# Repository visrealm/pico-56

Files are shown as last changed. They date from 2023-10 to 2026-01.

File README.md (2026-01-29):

# PICO-56
My [HBC-56](https://github.com/visrealm/hbc-56), a 65C02/TMS9918A homebrew computer on a backplane, fully emulated on a Raspberry Pi Pico.

<p align="left"><a href="https://github.com/visrealm/hbc-56">HBC-56</a></p>

Emulating the following HBC-56 hardware
* 65C02 CPU
* 65C22 VIA
* TMS9918A VDP
* Dual AY-3-8910 PSGs
* Dual NES controller inputs
* PS/2 keyboard input
* 96KB Banked RAM/ROM

Making use of my various emulation libraries (and more):

* [vrEmu6502](https://github.com/visrealm/vrEmu6502) - 6502/65C02 CPU emulation library (C99)
* [vrEmu6522](https://github.com/visrealm/vrEmu6522) - 6522/65C22 VIA emulation library (C99)
* [vrEmuTms9918](https://github.com/visrealm/vrEmuTms9918) - TMS9918A/TMS9929A VDP emulation library (C99)

Follow along on YouTube here: [youtube.com/@TroySchrapel](https://youtube.com/@TroySchrapel)

## Build Status

| | Windows | Linux | macOS |
|---|---|---|---|
| **Pico** |  |  |  |
| **Pico2** |  |  |  |

## Development environment

To build PICO-56, you'll need:
- CMake 3.12 or later
- ARM cross-compilation toolchain
- Python 3.x with Pillow library
- Git with submodules support

### Quick Start
 
```bash
git clone --recursive https://github.com/visrealm/pico-56.git
cd pico-56 && mkdir build && cd build
cmake -DCMAKE_BUILD_TYPE=Release -DPICO_SDK_FETCH_FROM_GIT=ON ..
make -j4  # Linux/macOS
```

For detailed platform-specific build instructions, troubleshooting, and advanced options, see **[BUILDING.md](BUILDING.md)**.

## Episodes
In the Episodes, I build the code from the ground up and provide a number of working demos. These are a work in progress with more to come as the videos come out.
#### [Episode 1 - VGA](episodes/ep01-vga)
In this episode, I build a VGA circuit on the Raspberry Pi Pico and write an intitial generic VGA output library and a number of VGA test programs from a test pattern through to moving sprites and an 800x600 framebuffer.

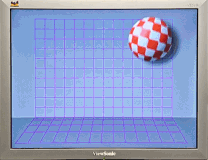
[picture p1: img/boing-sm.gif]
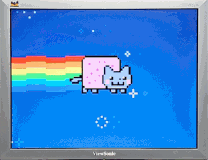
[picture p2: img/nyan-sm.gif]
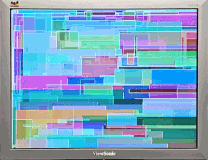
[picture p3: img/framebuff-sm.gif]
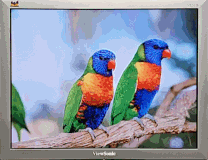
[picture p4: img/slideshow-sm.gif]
[](episodes/ep01-vga/ep01-vga-04-boing)  [](episodes/ep01-vga/ep01-vga-05-nyancat)  [](episodes/ep01-vga/ep01-vga-06-framebuffer)  [](episodes/ep01-vga/ep01-vga-09-slideshow)

#### [Episode 2 - TMS9918A](episodes/ep02-tms)
In this episode, I incorporate my TMS9918 library and create some test programs to test the TMS9918 functionality on the Pi Pico.

## Complete kits

Complete PICO-56 kits are now available on Tindie:





Also featured in HackerBox 0103 for those in the US:



## Gerbers

Gerbers for the PICO-56 v1.4 are now available. See [/schematics](schematics)

If you would like to support this project, you can [order your PCBs from my PCBWay project link](https://www.pcbway.com/project/shareproject/PICO_56_Retro_Computer_on_a_Pi_Pico_515c59b8.html)

## Schematics

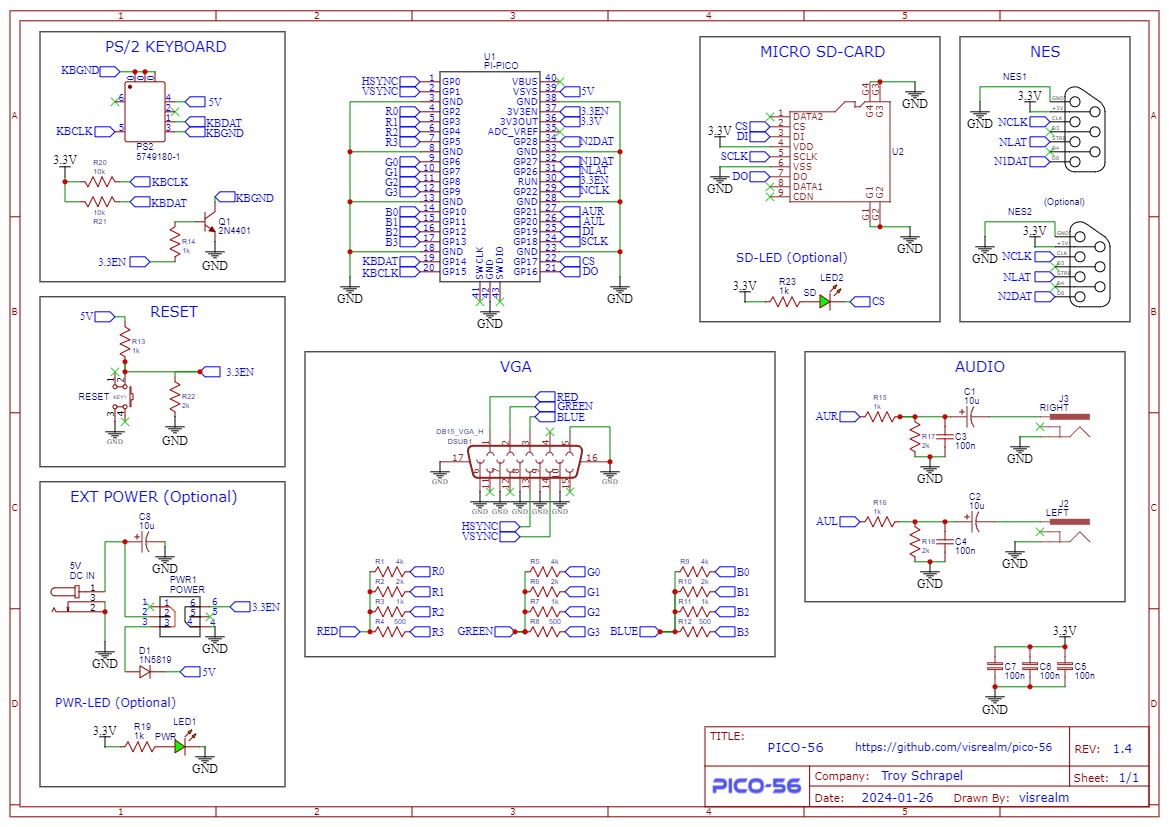
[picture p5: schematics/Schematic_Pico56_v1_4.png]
PICO-56 v1.4
<p align="left"></p>

## Bill of materials

| Qty. | Description | Code |
|---|---|---|
| 1 | PICO-56 PCB | PCB |
| 5 | 100nf (104) ceramic capacitor | C3,C4,C5,C6,C7 |
| 3 | 10uf (106) electrolytic capacitor | C8,C1,C2 |
| 3 | 4kΩ 0.25w resistor (3.9kΩ ok) | R1,R5,R9 |
| 2 | 10kΩ 0.25w resistor | R20,R21 |
| 6 | 2kΩ 0.25w resistor | R22,R2,R6,R10,R17,R18 |
| 9 | 1kΩ 0.25w resistor | R3,R7,R11,R13,R14,R15,R16,R19,R23 |
| 3 | 500Ω 0.25w resistor (510Ω ok) | R4,R8,R12 |
| 1 | 2N4401 transistor | Q1 |
| 1 | 1N5819 diode | D1 |
| 1 | Blue LED | LED1 |
| 1 | Green LED | LED2 |
| 1 | Push button | KEY1 |
| 1 | Push button (locking) | PWR1 |
| 1 | Barrel jack connector | 5V |
| 1 | VGA connector | DSUB1 |
| 2 | RCA connector | J2,J3 |
| 2 | NES connector | NO1,NO2 |
| 1 | PS/2 connector | PS2 |
| 1 | Raspberry Pi Pico (plus headers)  | U1 |
| 1 | MicroSD card connector | U2 |

There is a more detailed BOM in the [/schematics](schematics) folder. Alternatively, I have created a [Mouser project](https://www.mouser.com/ProjectManager/ProjectDetail.aspx?AccessID=8431486f76) for this which contains everything except for the NES connectors which can be obtained from AliExpress.

## 3D Printed case

A 3D printed case is available. All STLs are in the [/case](case) directory.

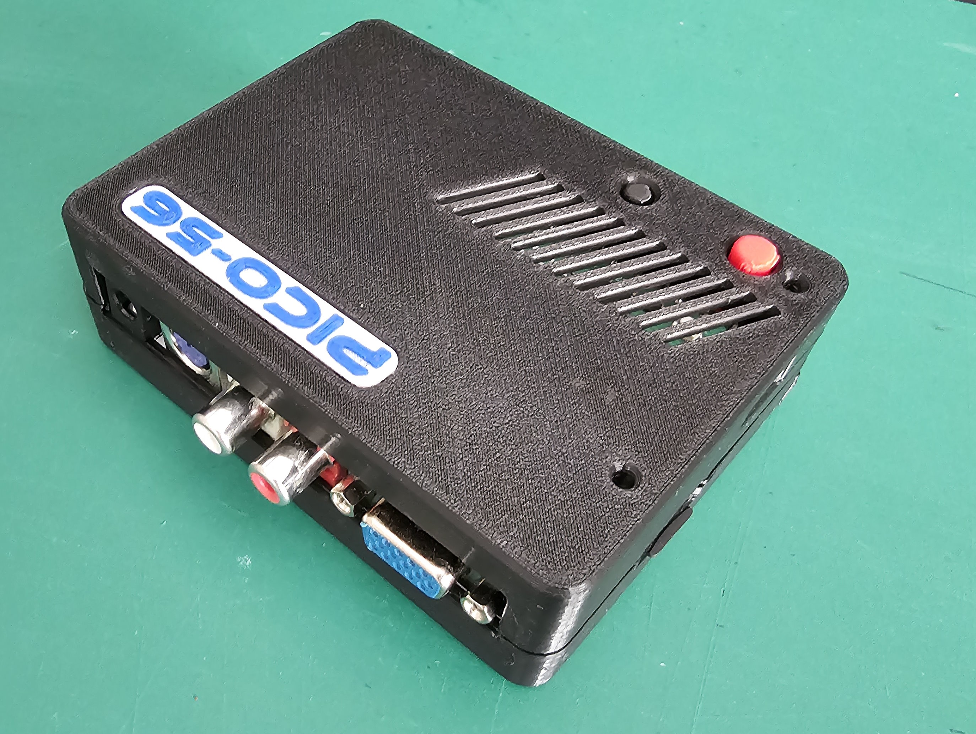
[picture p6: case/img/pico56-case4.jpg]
PICO-56 case
<p align="left"></p>

## Videos
PICO-56 - Introduction (https://www.youtube.com/watch?v=Nj_KkYn7YaA)

PICO-56 - Full Kit Build (https://www.youtube.com/watch?v=1hwMNQ1DXIU)

### Thanks

Thanks to [PCBWay](https://pcbway.com/g/186WQ9) for supporting this project.

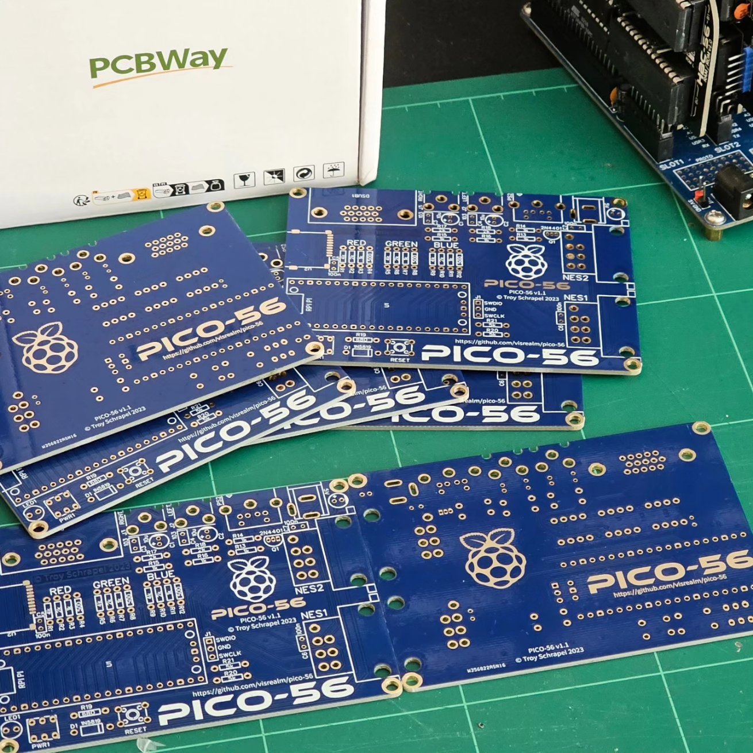
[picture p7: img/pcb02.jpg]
PICO-56
<p align="left"></p>

## Resources

* [Windows Development Environment Installer](https://github.com/raspberrypi/pico-setup-windows/releases)
* [Raspberry Pi Pico C/C++ SDK (PDF)](https://datasheets.raspberrypi.com/pico/raspberry-pi-pico-c-sdk.pdf)
* [HBC-56 Project](https://github.com/visrealm/hbc-56)
* [vrEmu6502 - 6502 CPU Emulation Library](https://github.com/visrealm/vrEmu6502)
* [vrEmu6522 - 6522 VIA Emulation Library](https://github.com/visrealm/vrEmu6522)
* [vrEmuTms9918 - TMS9918A VDP Emulation Library](https://github.com/visrealm/vrEmuTms9918)

## License
This code is licensed under the [MIT](https://opensource.org/licenses/MIT "MIT") license

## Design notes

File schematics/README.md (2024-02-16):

# Schematics

Version 1.4 of the schematic and [gerbers](Gerber_PCB_Pico56_v1_4.zip) are avilable now. 



## Changelog

#### v1.4

* Removed Raspberry Pi logo
* Added PCBWay logo

#### v1.3

* Fixed reversed transistor Q1
* Increased distance between R23 and mounting hole
* Increased hole size for power switch pins

#### v1.2

* Initial public release

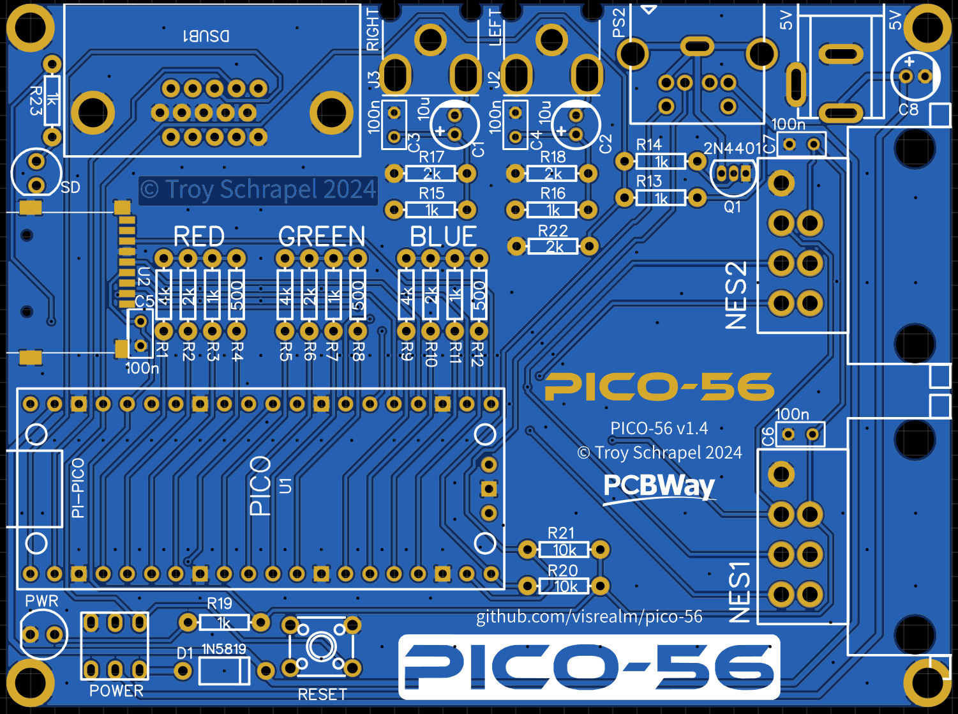
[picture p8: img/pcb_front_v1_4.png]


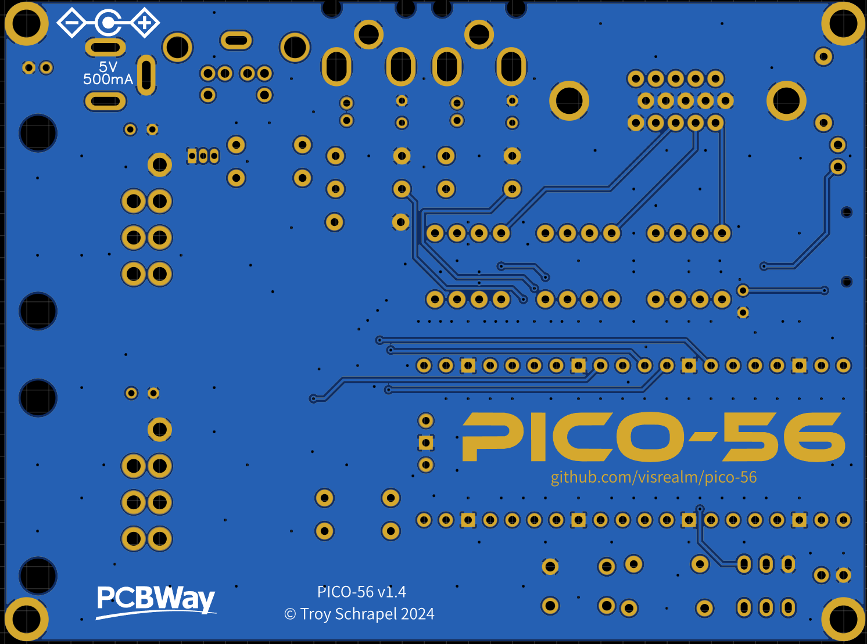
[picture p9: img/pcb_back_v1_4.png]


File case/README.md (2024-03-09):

## 3D Printed Case

I've had a first pass at designing a 3D printed case for the PICO-56. The PCB wasn't really designed with a case in mind, so there are some compromises. Primarily, it doesn't screw together. It clips together.

### Print details

* 0.2mm layer height
* Supports to bed only
* Top and base printed with flat surface down
* Buttons printed on their sides with supports and raised 0.2mm
* Badge printed with a pause for filament swap
* Photos from Creality Ender 3 V3 KE using 1.75mm Creality Hyper Series PLA

### Threaded inserts

The threaded inserts I've used are M3.5x5.7x4.6

### Gallery

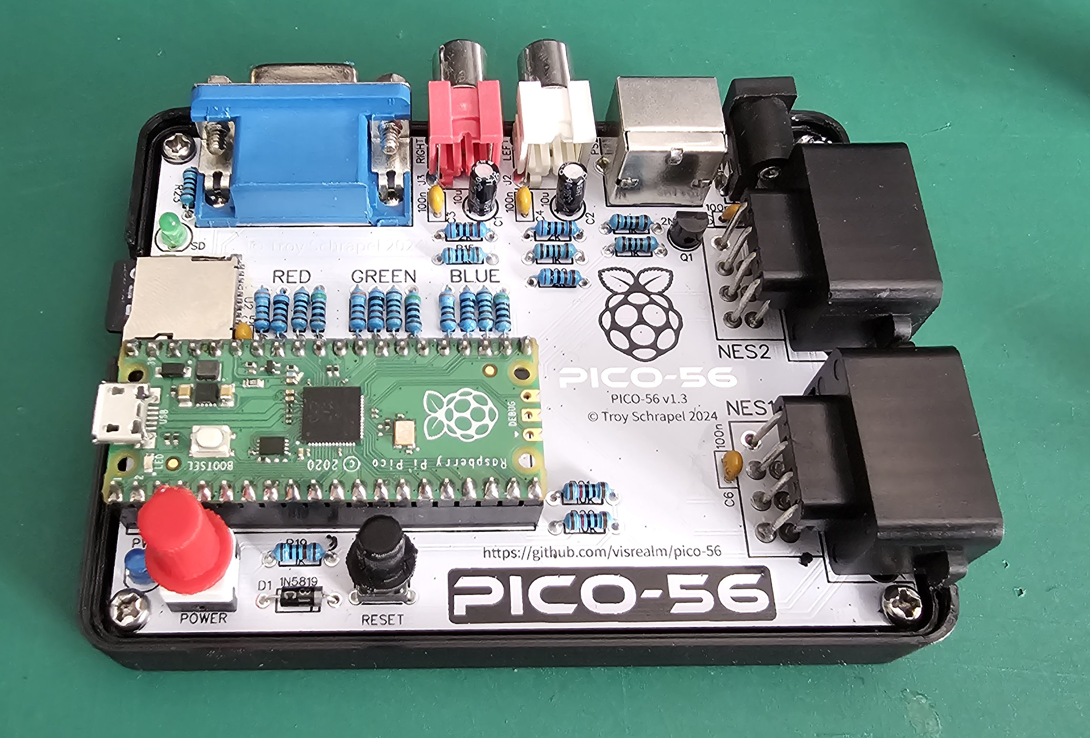
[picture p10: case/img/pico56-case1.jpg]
PICO-56 - Case

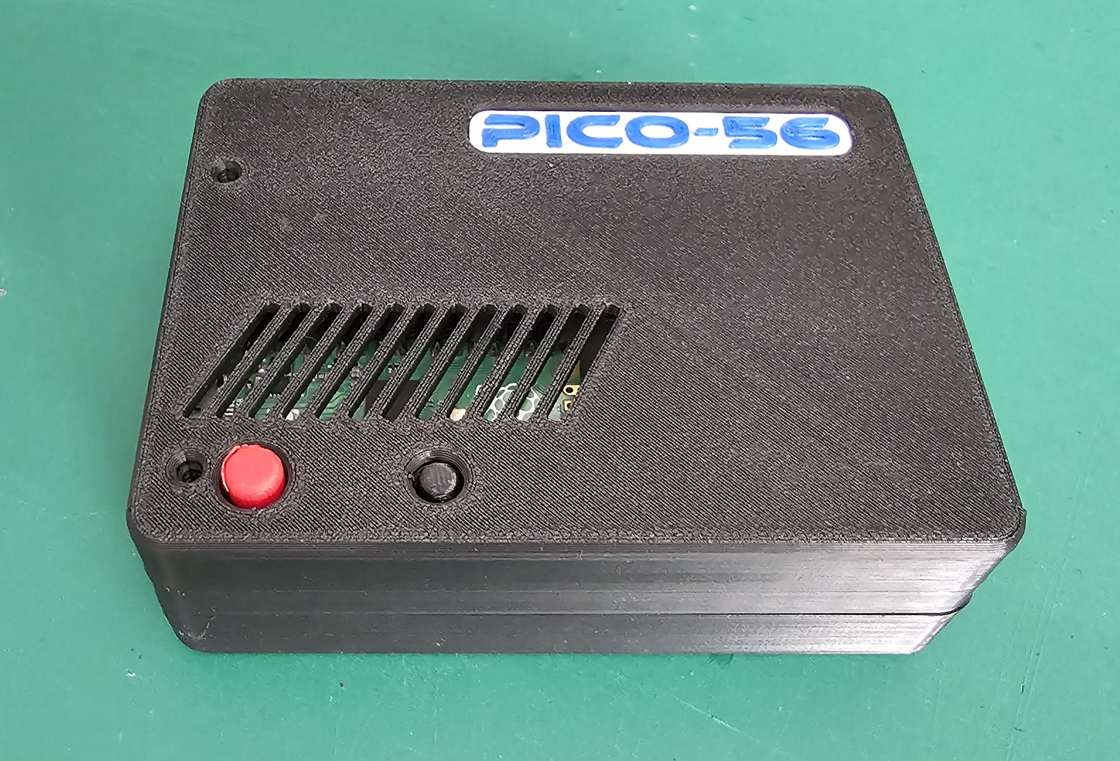
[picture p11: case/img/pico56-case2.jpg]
PICO-56 - Case

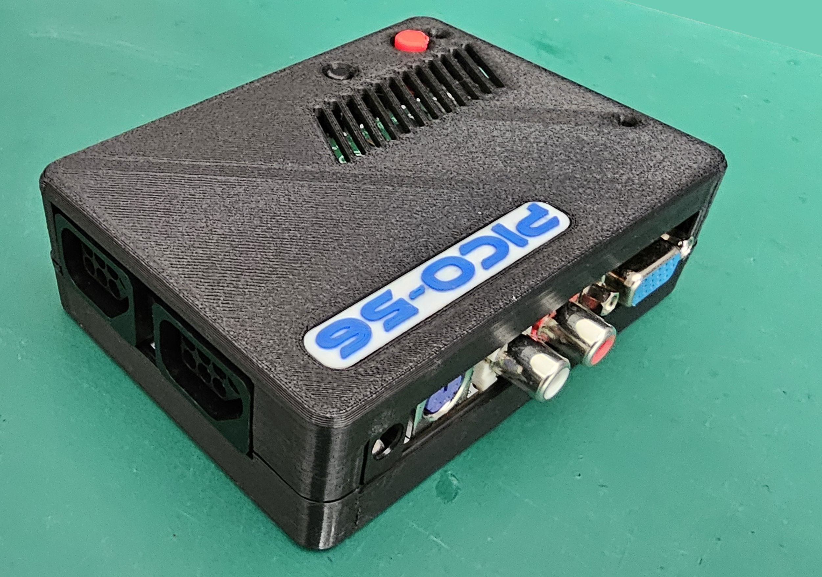
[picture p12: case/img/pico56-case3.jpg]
PICO-56 - Case

PICO-56 - Case
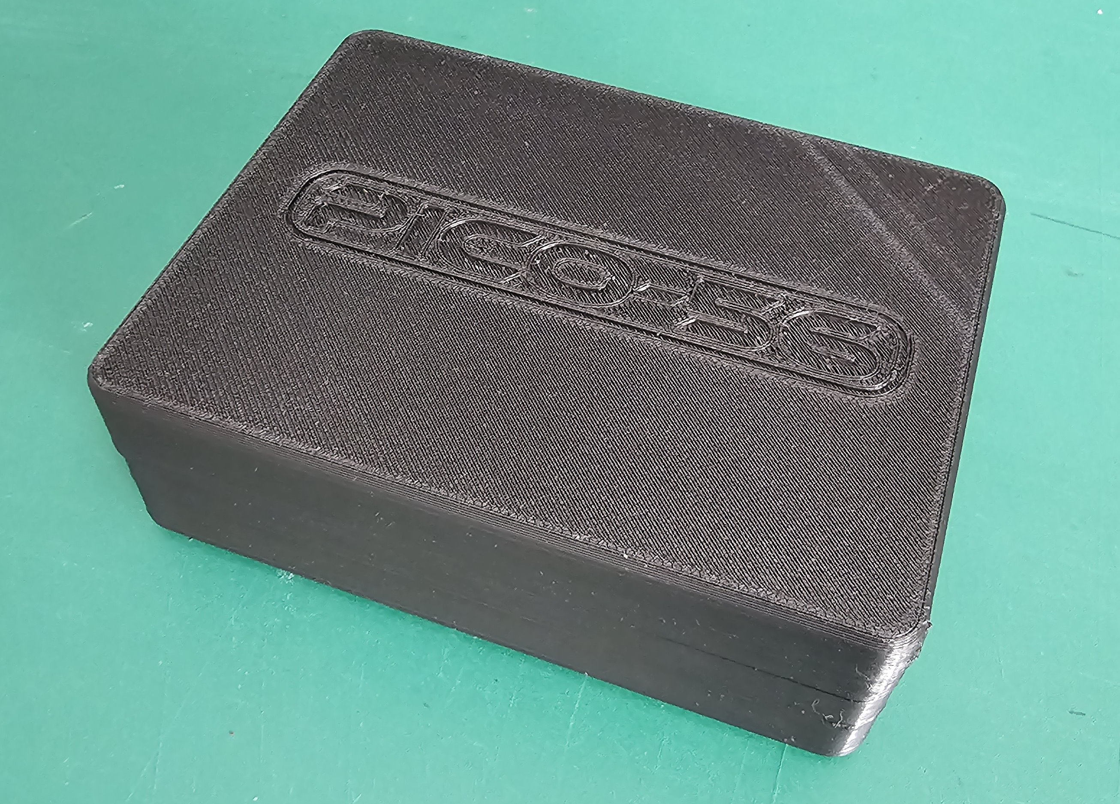
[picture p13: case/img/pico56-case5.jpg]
PICO-56 - Case


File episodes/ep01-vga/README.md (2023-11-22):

# Episode 1 - VGA

In this episode, I build a VGA circuit on the Pico and write an intitial generic VGA output library and a number of VGA test programs from a test pattern through to moving sprites and an 800x600 framebuffer.

## Schematic

For this episode, we start the build by adding a VGA connector and a reset button to the Pico. 

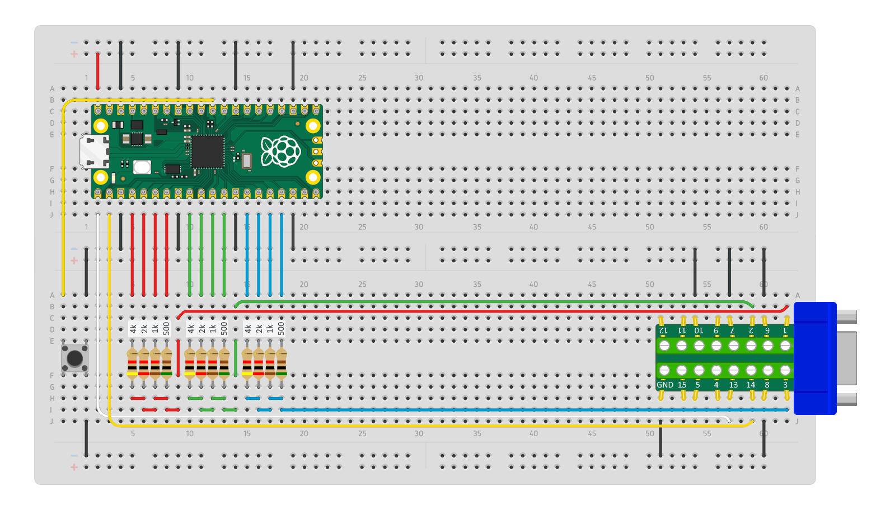
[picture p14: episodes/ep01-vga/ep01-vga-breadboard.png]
VGA on Breadboard


Full schematic here: [ep01-vga-schematic.pdf](ep01-vga-schematic.pdf)

## Example programs

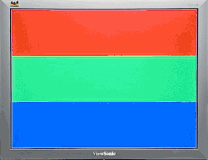
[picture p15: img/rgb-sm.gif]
rgb example video
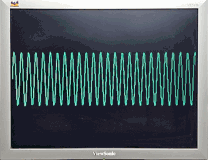
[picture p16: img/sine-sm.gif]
sine example video
| **[00 - VGA Sync](ep01-vga-00-sync)<br><br>Introduction to using the Pi Pico's Programmable Input/Output (PIO) to generate a configurable VGA sync signal.<br>**  | **[01 - VGA RGB](ep01-vga-01-rgb)<br><br><br>Adding a second PIO state machine to handle the VGA's RGB signals. Fill the VGA display with a solid color.** | **[03 - Sine Wave](ep01-vga-03-sine)<br><br><br>Generate an animated sine wave on the display.** |
|:--:|:--:|:--:|
| **[04 - Boing](ep01-vga-04-boing)<br><br>boing example video<br>The classic Commodore Amiga Boing demo. Showing animated sprites.** | **[05 - Nyan Cat](ep01-vga-05-nyancat)<br><br>nyan example video<br>It's a meme. The Nyan Cat.** | **[06 - Frame Buffer](ep01-vga-06-framebuffer)<br><br>framebuffer example video<br>Here, we use a 320x240x12bpp framebuffer to output graphics.** |
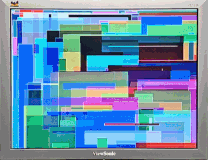
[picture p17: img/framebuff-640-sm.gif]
framebuffer 640x480 example video
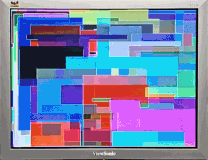
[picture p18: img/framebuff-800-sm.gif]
framebuffer 800x600 example video
| **[07 - Frame Buffer (640 x 480)](ep01-vga-07-framebuffer-640)<br><br><br>We can't fit a 640x480x12bpp framebuffer, but we can do 4bpp using a palette.** | **[08 - Frame Buffer (800 x 600)](ep01-vga-08-framebuffer-800)<br><br><br>Can we push it to 800 x 600?** | **[09 - Slideshow](ep01-vga-09-slideshow)<br><br>slideshow example video<br>A picture show** |

## VGA library

This VGA code is much more capable that is required for the future emulation of the TMS9918A and could be used stand-alone. This is the interface:

```c++
typedef void (*vgaScanlineFn)(uint16_t y, uint16_t pixels[VGA_VIRTUAL_WIDTH]);

typedef struct
{
  vgaScanlineFn scanlineFn;
} VgaInitParams;

void vgaInit(VgaInitParams params);
```

To use the library, you just need to implement a `vgaScanlineFn()` function which could be as simple as copying out data from a framebuffer:

```c++
/* my framebuffer */
uint16_t __aligned(4) frameBuffer[VGA_VIRTUAL_WIDTH * VGA_VIRTUAL_HEIGHT];

/* my scanline function - copy from my framebuffer */
void frameBufferScanline(uint16_t y, uint16_t pixels[VGA_VIRTUAL_WIDTH])
{
  memcpy(pixels, frameBuffer + y * VGA_VIRTUAL_WIDTH, VGA_VIRTUAL_WIDTH * sizeof(uint16_t));
}
```

Example `main()` function to initialize the VGA using the above framebuffer implementation:

```c++
int main(void)
{
  /* set up my VGA */
  VgaInitParams params;
  params.scanlineFn = frameBufferScanline;
  vgaInit(params);
  
  /* TODO: write to my framebuffer here */

  while (1)
  {
    /* TODO: or even in here */
	
    tight_loop_contents();
  }

  return 0;
}
```

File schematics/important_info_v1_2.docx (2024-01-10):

IMPORTANT INFORMATION

PCB v1.2

1. Transistor Q1 should be reversed. Mount with the flat side of the transistor facing the bottom of the PCB.

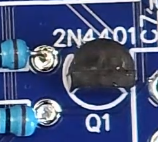
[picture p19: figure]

2. Capacitors C3 and C4 are marked 103. The supplied 100nF (104) capacitors should be used here.

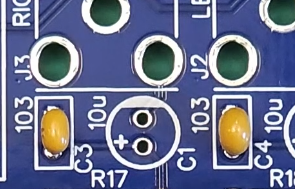
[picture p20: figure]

For latest information, firmware, software, tutorials, check out:

GitHub: https://github.com/visrealm/pico-56

YouTube: https://youtube.com/@TroySchrapel

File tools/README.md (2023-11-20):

Any custom tools required for the project go here:

# [img2carray.py](img2carray.py)

An image converter. Converts images into C arrays for direct use in a PICO-56 program.

The format of the image data will be `const uint16_t[]` for 24 or 32 bit images and will be a combined `const uint16_t[]` for the palette and a `const uint8_t[]` at 4 bits per pixel for 16 color paletized images and 8 bits per pixel for 256 color paletized images.

Alpha values are also supported.

The output format is `0bAAAABBBBGGGGRRRR` or `0xABGR`.

## Dependencies

The script requires the [Pillow Imaging Library](https://pypi.org/project/Pillow/).

Installation:

```sh
python3 -m pip install --upgrade Pillow
```

## Usage

```sh
python3 img2carray.py [-h] [-v] [-p PREFIX] [-o OUT] [-r RAM [RAM ...]] [-i IN [IN ...]]

Convert images into C-style arrays for use with the PICO-56.

options:
  -h, --help            show this help message and exit
  -v, --verbose         verbose output
  -p PREFIX, --prefix PREFIX
                        array variable prefix
  -o OUT, --out OUT     output file - defaults to base input file name with .c extension
  -r RAM [RAM ...], --ram RAM [RAM ...]
                        input file(s) to store in Pi Pico RAM - can use wildcards
  -i IN [IN ...], --in IN [IN ...]
                        input file(s) to store in Pi Pico ROM - can use wildcards
```

### input

A filename or glob (wildcards) to convert. By default, the arrays will be stored in the Pi Pico flash/ROM. TO have an image array assigned to be stored in RAM, pass it in using the -r / --ram command-line prefix.

### output

Optional parameter to specify a single output file.

By default, the output files will be named the same as the input file(s) with a .c/.h extension. This option allows you to combine multiple images into a single C source. A header file of the same name is also generated.

## Example usage

```sh
python img2carray.py -i res/*.png -o images.c
```

Will generate images.c and images.h containing all .png images in the res directory.

## CMake integration

[The root CMakeLists.txt](../CMakeLists.txt) contains a `visrealm_generate_image_source()` function which can be used to integrate this tool into your build process.

```sh
visrealm_generate_image_source(<program-name> <output-file> <rom-images> [<ram-images>])
```

Here is an example usage in your project's CMakeLists.txt:

```sh
visrealm_generate_image_source(${PROGRAM} images res/*.png res/myramimage.png)
```

This function will generate the C source file(s) from the input images and also add the .c file to the `target_sources()`. The generated file(s) will be placed in yout project's build directory.

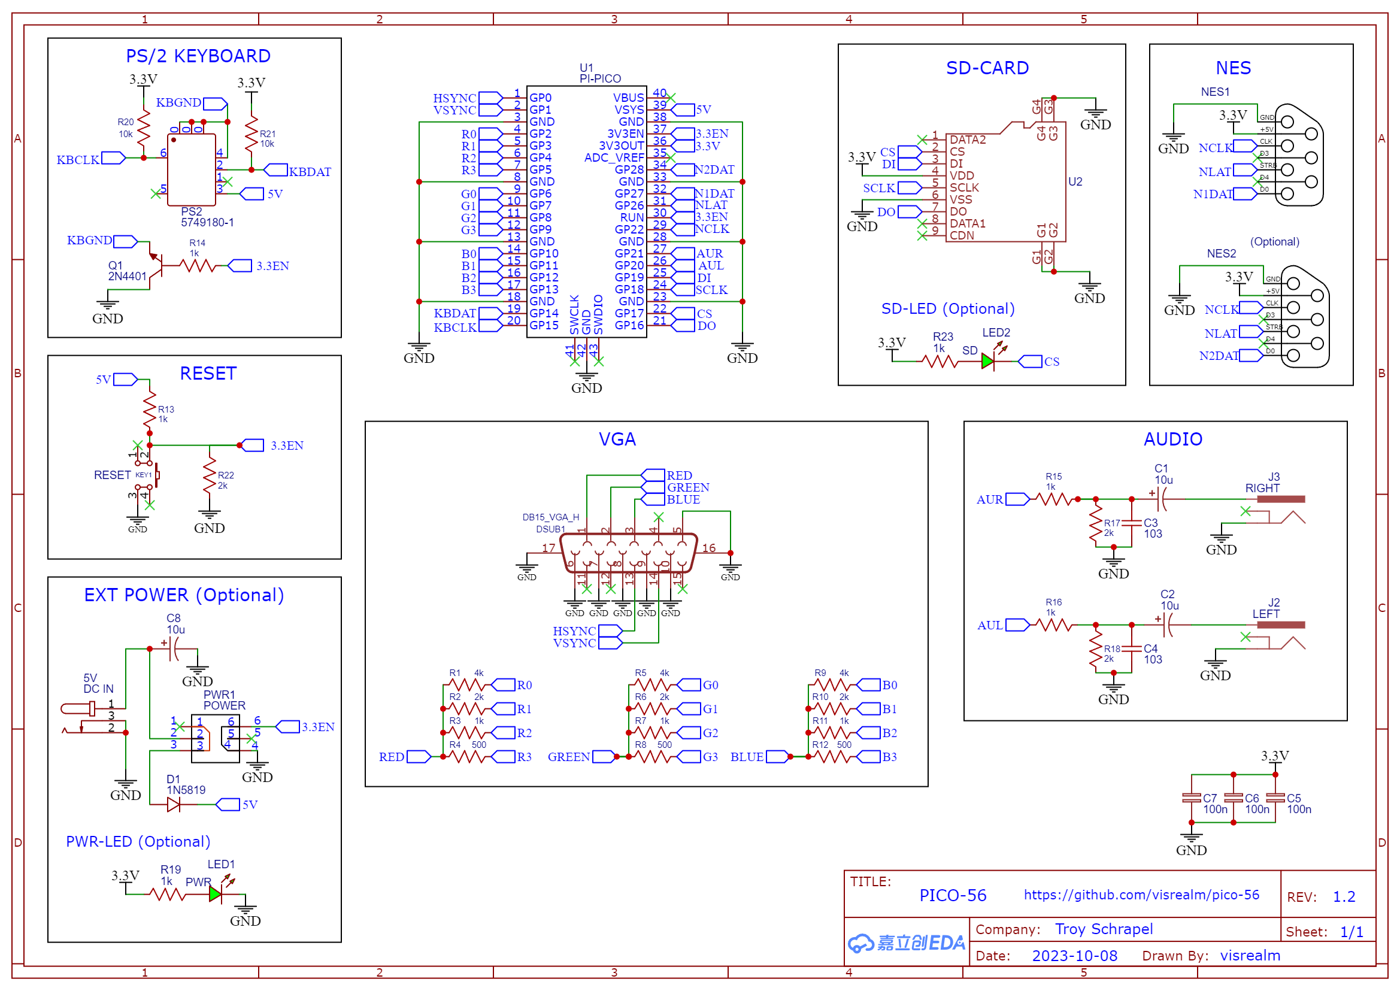
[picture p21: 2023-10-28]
schematics/Schematic_Pico56_v1_2.png

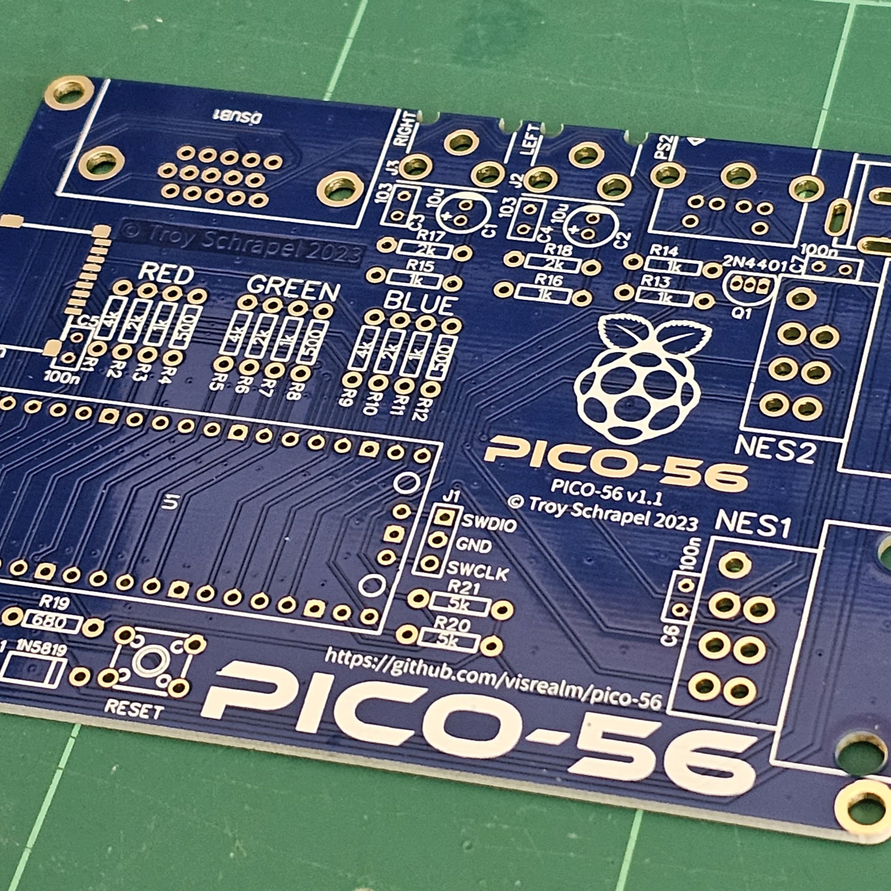
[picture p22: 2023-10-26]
img/pcb01.jpg

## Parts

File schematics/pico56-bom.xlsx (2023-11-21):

ID | Name | Designator | Footprint | Quantity | Manufacturer Part | Manufacturer
1 | PI-PICO | U1 | RASPBERRY-PI-PICO | 1 | SC0915 | Raspberry Pi
2 | SD | LED2 | LED-TH_BD5.0_GREEN | 1 | 333-2SYGD/S530-E2 | EVERLIGHT(台湾亿光)
3 | 1k | R3,R7,R11,R13,R14,R15,R16,R19,R23 | R_AXIAL-0.3 | 9 | MFR-25FTF52-1K | YAGEO
4 | POWER | PWR1 | PB22E08 | 1 | MHPS2285 | APEM
5 | NO | U2 | TF-SMD_TFCARD_ST-TF-003J | 1 | ST-TF-003A
6 | 2k | R22,R2,R6,R10,R17,R18 | R_AXIAL-0.3 | 6 | MFR-25FTF52-2K | YAGEO
7 | 10k | R20,R21 | R_AXIAL-0.3 | 2 | MFR-25FTF52-10K | YAGEO
8 | 10u | C8,C1,C2 | CAP-D5.0×F2.0 | 3 | ESK106M016AC3AA | KEMET
9 | 100n | C5,C6,C7 | RAD-0.1 | 3 | K104K10X7RF5TL2 | Vishay
10 | NES1 | NO1 | NES CONTROLLER 7 PIN FEMALE CONNECTOR WITH MOUNT PEGS | 1 | 5056026433198 | ZedLabz
11 | LEFT | J2 | RCA | 1 | PJRAN1X1U03AUX | Switchcraft
12 | RIGHT | J3 | RCA | 1 | PJRAN1X1U03AUX | Switchcraft
13 | NES2 | NO2 | NES CONTROLLER 7 PIN FEMALE CONNECTOR WITH MOUNT PEGS | 1 | 5056026433198 | ZedLabz
14 | DC IN | 5V | DC-IN-TH_DC005 | 1 | DC005-2.0MM | SOFNG
15 | 5749180-1 | PS2 | PS2-TH_6P-P2.05-S2.49_L12.8-W14.0-M | 1 | 5749180-1 | TE Connectivity
16 | RESET | KEY1 | KEY-TH_4P-L6.0-W6.0-P4.50-LS6.5 | 1 | K2-1102DP-E4SW-04 | 韩国韩荣
17 | 4k | R1,R5,R9 | R_AXIAL-0.3 | 3 | MFR-25FTF52-4K | YAGEO
18 | 500 | R4,R8,R12 | R_AXIAL-0.3 | 3 | MFR-25FTF52-500R | YAGEO
19 | 103 | C3,C4 | RAD-0.1 | 2 | K103K10X7RF5UL2 | Vishay
20 | 2N4401 | Q1 | TO-92-3_L5.1-W4.1-P1.27-L | 1 | 2N3904 | SEMTECH
21 | PWR | LED1 | LED-TH_BD5.0_GREEN | 1 | 333-2SYGD/S530-E2 | EVERLIGHT(台湾亿光)
22 | 1N5819 | D1 | DO-41_BD2.4-L4.7-P8.70-D0.9-RD | 1 | 1N4007W | BLUE ROCKET
23 | DB15_VGA_H | DSUB1 | DB15-VGA-H | 1 | L77HDE15SD1CH4R | Amphenol

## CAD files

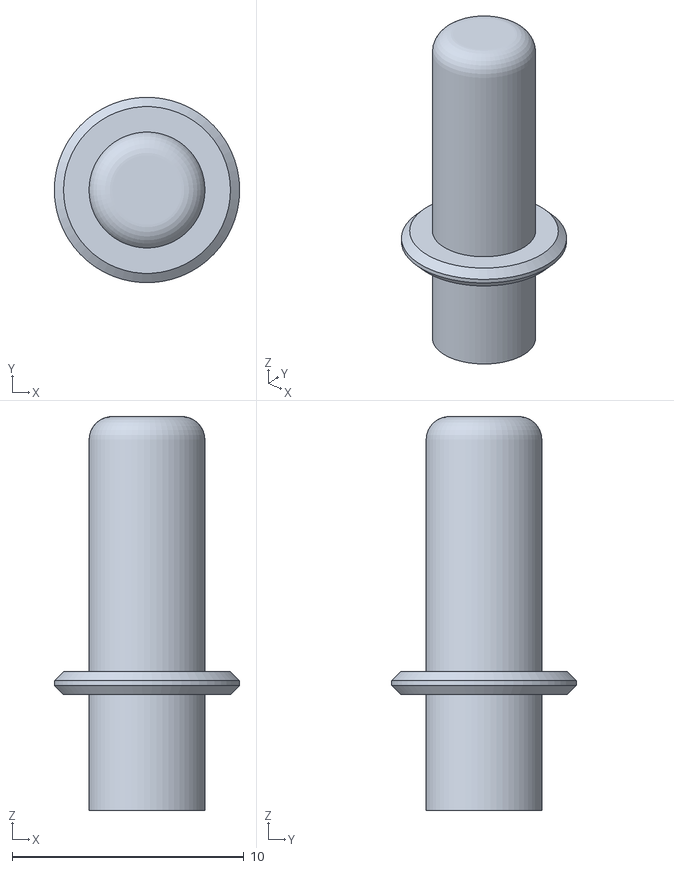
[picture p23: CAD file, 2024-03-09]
case/p56-reset-v1-5.stl
8.00 x 7.99 x 17.0

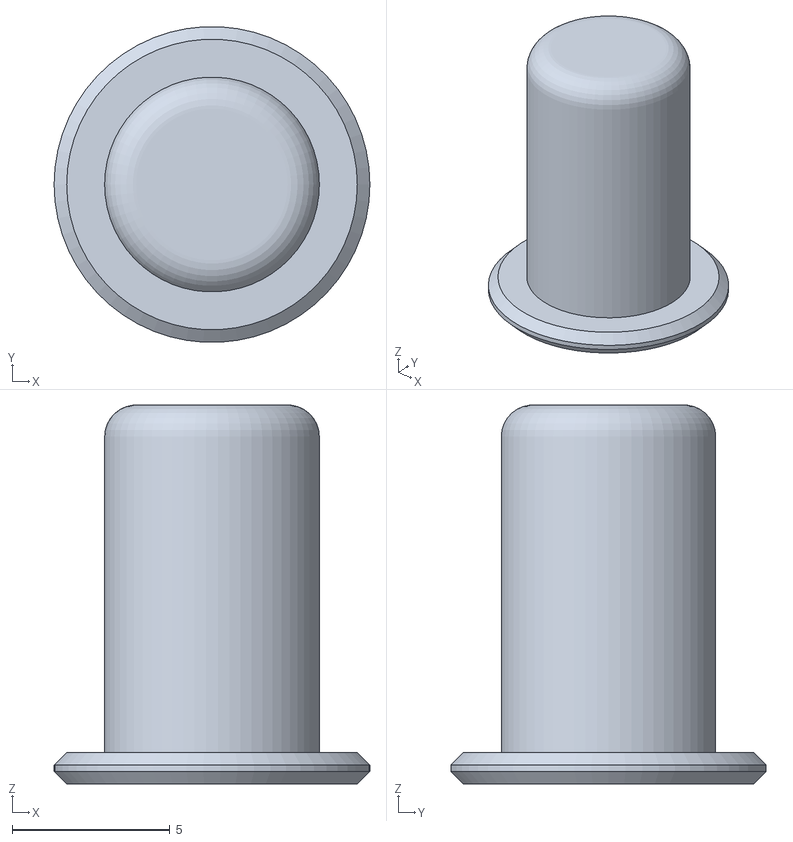
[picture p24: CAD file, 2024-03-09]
case/p56-power-v1-5.stl
10.00 x 9.99 x 12.0

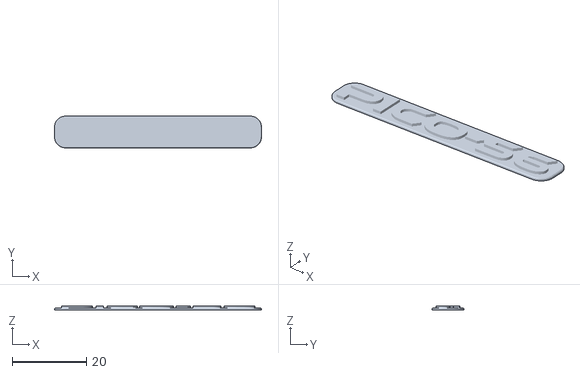
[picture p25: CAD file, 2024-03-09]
case/p56-badge-v1-5.stl
55.9 x 8.60 x 1.20

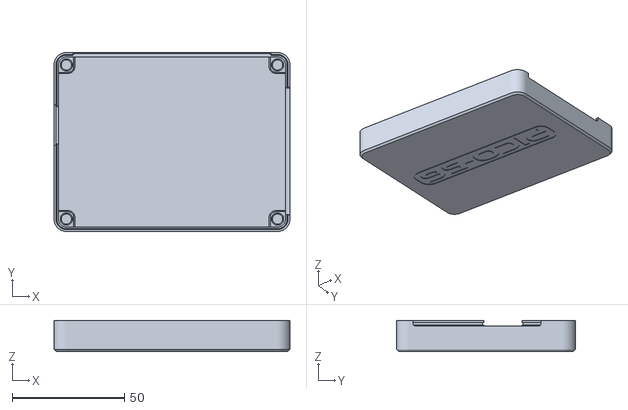
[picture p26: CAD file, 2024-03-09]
case/p56-bottom-v1-5.stl
105.1 x 79.7 x 14.0

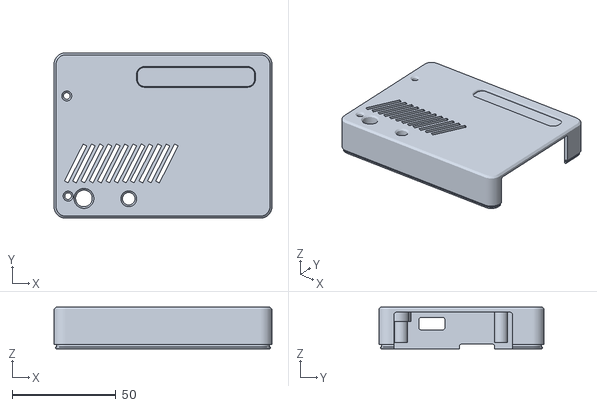
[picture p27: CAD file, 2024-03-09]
case/p56-top-v1-5.stl
105.1 x 79.7 x 20.2

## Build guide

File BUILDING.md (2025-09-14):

# Building PICO-56

This document provides detailed build instructions for the PICO-56 project on different platforms.

## Prerequisites

All platforms require:
- CMake 3.12 or later
- Python 3.x with Pillow library
- ARM cross-compilation toolchain
- Git (with submodules support)

## Windows

### Using the Raspberry Pi Pico VS Code Extension

1. Install [Visual Studio Code](https://code.visualstudio.com/)
2. Install the [Raspberry Pi Pico extension](https://marketplace.visualstudio.com/items?itemName=raspberry-pi.raspberry-pi-pico) from the VS Code marketplace
3. The extension will automatically guide you through installing:
   - Pico SDK
   - ARM GCC toolchain
   - CMake and build tools
   - Python dependencies (including Pillow)

### Building on Windows

#### With VS Code Extension (Recommended)
1. Clone the repository:
   ```cmd
   git clone --recursive https://github.com/visrealm/pico-56.git
   ```
2. Open the `pico-56` folder in VS Code
3. The Pico extension will automatically configure the project
4. Use the extension's build commands or press `Ctrl+Shift+P` and run "Pico: Build"

#### Command Line Building
If you need to build from the command line:
1. Clone the repository:
   ```cmd
   git clone --recursive https://github.com/visrealm/pico-56.git
   cd pico-56
   ```

2. Create build directory and configure:
   ```cmd
   mkdir build
   cd build
   cmake .. -DCMAKE_BUILD_TYPE=Release -DPICO_SDK_FETCH_FROM_GIT=ON
   ```

3. Build:
   ```cmd
   cmake --build . --config Release
   ```

## Linux

### Install Dependencies

#### Ubuntu/Debian:
```bash
sudo apt-get update
sudo apt-get install -y cmake gcc-arm-none-eabi libnewlib-arm-none-eabi build-essential git python3 python3-pip
pip3 install Pillow
```

#### Fedora/RHEL:
```bash
sudo dnf install cmake arm-none-eabi-gcc-cs arm-none-eabi-newlib git python3 python3-pip
pip3 install Pillow
```

#### Arch Linux:
```bash
sudo pacman -S cmake arm-none-eabi-gcc arm-none-eabi-newlib git python python-pip
pip install Pillow
```

### Building on Linux

1. Clone the repository:
   ```bash
   git clone --recursive https://github.com/visrealm/pico-56.git
   cd pico-56
   ```

2. Create build directory and configure:
   ```bash
   mkdir build && cd build
   cmake .. -DCMAKE_BUILD_TYPE=Release -DPICO_SDK_FETCH_FROM_GIT=ON
   ```

3. Build:
   ```bash
   make -j$(nproc)
   ```

## macOS

### Install Dependencies

1. Install Homebrew if not already installed:
   ```bash
   /bin/bash -c "$(curl -fsSL https://raw.githubusercontent.com/Homebrew/install/HEAD/install.sh)"
   ```

2. Install required packages:
   ```bash
   brew install cmake python3
   brew install --cask gcc-arm-embedded
   pip3 install Pillow
   ```

### Building on macOS

1. Clone the repository:
   ```bash
   git clone --recursive https://github.com/visrealm/pico-56.git
   cd pico-56
   ```

2. Create build directory and configure:
   ```bash
   mkdir build && cd build
   cmake .. -DCMAKE_BUILD_TYPE=Release -DPICO_SDK_FETCH_FROM_GIT=ON
   ```

3. Build:
   ```bash
   make -j$(sysctl -n hw.ncpu)
   ```

## Board Variants

The project supports both Raspberry Pi Pico and Pico2. To build for a specific board:

### For Raspberry Pi Pico (default):
```bash
cmake .. -DCMAKE_BUILD_TYPE=Release -DPICO_BOARD=pico -DPICO_SDK_FETCH_FROM_GIT=ON
```

### For Raspberry Pi Pico2:
```bash
cmake .. -DCMAKE_BUILD_TYPE=Release -DPICO_BOARD=pico2 -DPICO_SDK_FETCH_FROM_GIT=ON
```

## Build Outputs

After a successful build, you'll find the following files in the build directory:

- `**/*.uf2` - UF2 files for flashing to the Pico
- `**/*.bin` - Binary files
- `**/*.elf` - ELF executable files

## Flashing to Hardware

1. Hold the BOOTSEL button on your Raspberry Pi Pico while connecting it to your computer via USB
2. The Pico will appear as a USB mass storage device
3. Copy the desired `.uf2` file to the Pico
4. The Pico will automatically reboot and run your program

## Troubleshooting

### Common Issues

#### Missing Python Dependencies
If you get errors about missing PIL/Pillow:
```bash
pip install Pillow
# or on some systems:
pip3 install Pillow
```

#### ARM Toolchain Issues on macOS
If you encounter "cannot read spec file 'nosys.specs'" errors:
```bash
# Uninstall problematic installations
brew uninstall --force arm-none-eabi-gcc arm-none-eabi-binutils
# Install the complete toolchain
brew install --cask gcc-arm-embedded
```

#### CMake Cannot Find SDK
If CMake complains about not finding the Pico SDK, ensure you're using:
```bash
-DPICO_SDK_FETCH_FROM_GIT=ON
```

This will automatically download and configure the correct SDK version.

#### Submodule Issues
If you get errors about missing submodules:
```bash
git submodule update --init --recursive
```

## Building Individual Episodes

The project includes various episode examples in the `episodes/` directory. These are built automatically with the main project. To build only specific episodes, you can use:

```bash
# From the build directory
cmake --build . --target ep01-vga-01-test-pattern
cmake --build . --target ep01-vga-04-boing
# etc.
```

## Development Tips

- Use `CMAKE_BUILD_TYPE=Debug` for debugging builds
- Use `make -j$(nproc)` on Linux or `make -j$(sysctl -n hw.ncpu)` on macOS for parallel builds
- The build system will automatically handle PIO file generation and image conversion
- All dependencies are automatically downloaded when using `PICO_SDK_FETCH_FROM_GIT=ON`

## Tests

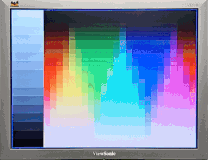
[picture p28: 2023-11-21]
img/testpatt-sm.gif

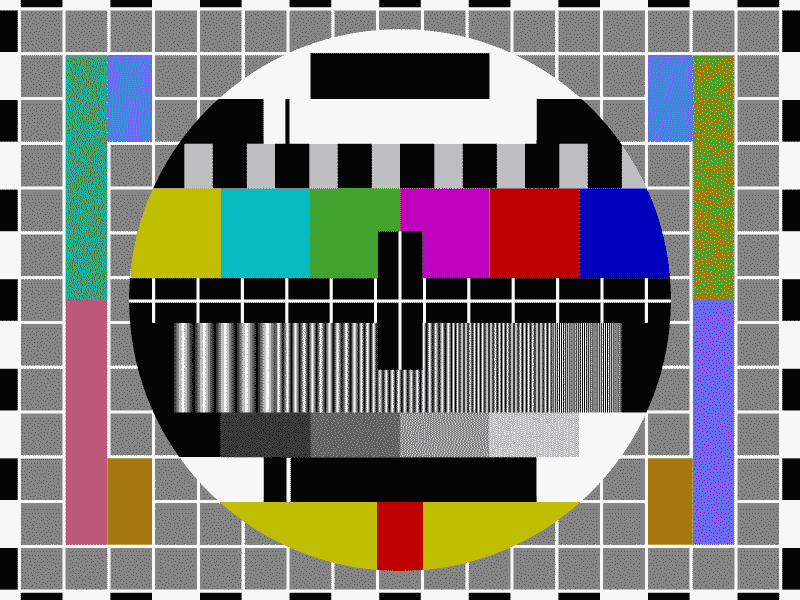
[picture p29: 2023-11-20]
episodes/ep01-vga/ep01-vga-08b-image-800/res/testpatt800x16.png

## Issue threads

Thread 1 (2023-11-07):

Is the AY-3-8910 Pico emulation code available?

cbmeeks, 2023-11-07:
I was wondering if you have released the source for your AY-3-8910 emulation on the Pico.  I am working on a similar project and would really love some information on that.  :-)

Thanks!

visrealm, 2023-11-07:
Hey CB. I'm working on the consumable version now. Here's some snippets from my existing dual AY-3-8910 emulation to get you started. I'm using [my fork of emu2149](https://github.com/visrealm/emu2149).

Globals / magic numbers:
```c
#define PWM_WRAP 1024
#define AUDIO_GPIO 20

PSG* psg0 = NULL;
PSG* psg1 = NULL;

uint audioSlice = 0;
```

Initialization (called once)
```c
void configureAudio()
{
  // init the two PSGs
  int sampleRate = vgaParams.hSyncParams.freqHz;   // I'm updating the audio in my VGA hsync blanking ~37.87KHz
  psg0 = PSG_new(PSG_CLOCK, sampleRate);
  psg1 = PSG_new(PSG_CLOCK, sampleRate);
  PSG_setVolumeMode(psg0, EMU2149_VOL_AY_3_8910);  // AY-3-8910 mode
  PSG_setVolumeMode(psg1, EMU2149_VOL_AY_3_8910);  // AY-3-8910 mode
  PSG_reset(psg0);
  PSG_reset(psg1);

  // init the GPIO pins for PWM
  gpio_set_function(AUDIO_GPIO , GPIO_FUNC_PWM);
  gpio_set_function(AUDIO_GPIO + 1, GPIO_FUNC_PWM);

  audioSlice = pwm_gpio_to_slice_num(AUDIO_GPIO );

  pwm_set_clkdiv_int_frac(audioSlice, 1, 0);
  pwm_set_wrap(audioSlice, PWM_WRAP);
  pwm_set_both_levels(audioSlice, 0, 0);
  pwm_set_enabled(audioSlice, true);
}
```

Updates (called in my hsync event handler at ~37.87KHz:
```c
PSG_calc(psg0);
PSG_calc(psg1);

// mix the various channels from the PSGs how you see fit
uint16_t leftAudio = abs((((int32_t)psg0->ch_out[0] + (int32_t)psg1->ch_out[1] + (int32_t)psg0->ch_out[2] + (int32_t)psg1->ch_out[2]))) * PWM_WRAP >> 14;
uint16_t rightAudio = abs((((int32_t)psg1->ch_out[0] + (int32_t)psg0->ch_out[1] + (int32_t)psg0->ch_out[2] + (int32_t)psg1->ch_out[2]))) * PWM_WRAP >> 14;

pwm_set_both_levels(audioSlice, leftAudio, rightAudio);
```

cbmeeks, 2023-11-08:
Thanks for the response.  I definitely have a lot to learn on this one.  My main goal is to have some sort of PSG from the Pico...all being controlled by a 6502.

visrealm, 2023-11-08:
Oh, so you're using a physical 6502? And the PICO is acting as the RAM/peripherals? One step I failed to mention was reading/writing from/to the virtual PSG(s).  Each PSG will need 3-4 addresses mapped. For example, all of my I/O is mapped at 0x7fxx and my PSGs are mapped at 0x7f40 and 0x7f44.  The way my PSGs are wired on my actual HBC-56, writing to 0x7f40 will latch a register to write to, 0x7f41 will write a register value and reading from 0x7f42 will read a value from the latched register. The address mappings don't matter, but you will need a similar process.

Here's some snippets from the PICO-56 memory read/write functions which show how the various addresses ling to the PSG_readreg/PSG_writereg functions:

```c
#define PSG0_BASE_PORT 0x40
#define PSG1_BASE_PORT 0x44

void cpuMemWrite(uint16_t addr, uint8_t val)
{
  if (addr < 0x7f00)  // RAM
  {
    ram[addr] = val;
  }
  else if (addr < 0x8000) // IO
  {
      switch (addr & 0xff)
      {
        case 0x10:
          vrEmuTms9918WriteData(tms9918, val);
          break;

        case 0x11:
          vrEmuTms9918WriteAddr(tms9918, val);
          break;

        case PSG0_BASE_PORT:
          psg0Reg = val;
          break;

        case PSG0_BASE_PORT | 0x01:
          PSG_writeReg(psg0, psg0Reg, val);
          break;

        case PSG1_BASE_PORT:
          psg1Reg = val;
          break;

        case PSG1_BASE_PORT | 0x01:
          PSG_writeReg(psg1, psg1Reg, val);
          break;

        default:
          // unknown device
          break;
    }
  }
}

uint8_t cpuMemRead(uint16_t addr)
{
  if (addr & 0x8000)     // ROM
  {
    return ROM[addr & 0x7fff];
  }
  else if (addr < 0x7f00)  // RAM
  {
    return ram[addr];
  }
  else    // IO
  {
      switch (addr & 0xff)
      {
        case 0x10:
          {
            return vrEmuTms9918ReadData(tms9918);
          }

        case 0x11:
          {
            uint8_t value = vrEmuTms9918ReadStatus(tms9918);
            releaseInterrupt(TMS_INT);
            return value;
          }

          // <snip> handle keyboard, nes, interrupt controller, etc.

        case PSG0_BASE_PORT | 0x02:
          {
            return PSG_readReg(psg0, psg0Reg);
          }

        case PSG1_BASE_PORT | 0x02:
          {
            return PSG_readReg(psg1, psg1Reg);
          }

        default:
          return 0x00;
      }
    }
  }
}
```

cbmeeks, 2023-11-08:
Thank you for this information!

Yeah, I am designing a new SBC with an actual 6502.  The Pico(s) will act as video, audio, etc.

I will dig into this more when I get back.  Headed out on a nice vacation tomorrow.

Thanks!

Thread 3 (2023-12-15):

Q1 (2N4401) question

g8kuw-tv, 2023-12-15:
Hi Troy - I have built a PICO-56, and it's almost working...

Is Q1 in the Pico-56 schematic shown the wrong way around? I can't see how KBD ground will be pulled low when 3v3 is present.

Thanks

Steve

g8kuw-tv, 2023-12-31:
Thanks Troy!

(I wasn't sure if this was an appropriate place to ask questions.)

vslinuxdotnet, 2024-01-18:
Hello,
Sorry about this question but, what is the propose of this transistor to enable GND in keyboard?
The 3v3_en is to enable (default) the PWD of 3.3v, witch is always high, so the transistor is always on.
Regards,
VS

visrealm, 2024-01-18:
The power and reset buttons are connected to 3.3v_en so the transistor effectively powers off the keyboard when the PICO-56 is "off" (or reset).

Closed 2023-12-31.

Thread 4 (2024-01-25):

Silkscreen / Parts List / Mouser Project not in sync

lloesche, 2024-01-25:
I (admittedly blindly) ordered 5 PCBs using the PCBWay link and 5x the Mouser Project. When assembling everything, I noticed that the silkscreen doesn't even mention 10nf caps, everything is 100nf. But in my Mouser order there were both values delivered. And I believe one of the resistor values was also a different quantity than what I expected based on the values on the board.

Would be good if silkscreen/PCBWay project, Github README, Mouser project, etc. were all in sync.

visrealm, 2024-01-27:
Hi, the parts you've ordered will work just fine with your PCBs. In later revision of the board, I changed the value of the two 10nF caps to 100nF to reduce part type count. The output/result will be almost identical between the two. For the mouser project, some part counts were increased to take advantage of Mouser's bulk pricing. eg. It's cheaper to order 10 of something than 9.

I will update the BOM to reflect later boards.

visrealm, 2024-01-27:
I've updated the Mouser project and BOM to reflect the later boards silkscreen. Have also changed *most* of the mouser project quantities to be actual rather than cheaper bulk discounted values except for the 1K resistors I kept at 10 rather than 9 as it's significantly cheaper that way.

Closed 2024-01-27.

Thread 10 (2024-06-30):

Hardware timers causes crash

cbmeeks, 2024-06-30:
I'm quite sure I have misconfigured the timer example I was trying, but it seems if you try to use one, the video output just stops.

I was mostly curious if you have run into this.

````
// code in vga.c

bool repeating_timer_callback(struct repeating_timer *t) {
    return true;
}

static void vgaLoop() {

    struct repeating_timer timer;
    add_repeating_timer_ms(500, repeating_timer_callback, NULL, &timer);

    while (1) {
        uint32_t message = multicore_fifo_pop_blocking();
        if (message & 0x01) {
            vgaParams.scanlineFn(message & 0xfff, rgbDataBufferOdd);
        } else {
            vgaParams.scanlineFn(message & 0xfff, rgbDataBufferEven);
        }
    }
}

````

visrealm, 2024-07-01:
I suspect the default alarm pool hardware timer IRQ handling is occurring on core 0. This is the same core which is handling the VGA DMA Interrupts (`dmaIrqHandler()`).

Note: `add_repeating_timer_ms()` is a wrapper for `alarm_pool_add_repeating_timer_us()` with `alarm_pool_get_default()` as the first argument.

You might need to manually create an alarm pool on core 1.

See

- https://www.raspberrypi.com/documentation//pico-sdk/group__repeating__timer.html
- https://www.raspberrypi.com/documentation/pico-sdk/group__alarm.html

visrealm, 2024-07-01:
Note: In the actual PICO-56 VGA code ( https://github.com/visrealm/pico-56/blob/main/src/devices/tms9918/vga/vga.c ) you can add a callback for the end of frame.
If you've still having issues using the hardware timer, you could use this to accumulate time in 16.67ms increments. There is also an end of scanline callback which I use to update the PWM audio. So, the PICO-56 audio frequency is tied to the VGA HSYNC frequency (~31KHz).

cbmeeks, 2024-07-01:
Ah, I didn't think about that.  I know very little about the timers on the Pico but I will study that some more.

But now that you mention it, I like the idea of the "end of frame" better anyway.  I needed a timer to flash a cursor but it makes more sense to just put a callback at the end of frame.

Thanks again for your help!  I will try not to pester you with things like this.  :-)

visrealm, 2024-07-02:
I don't mind. No problem at all.

cbmeeks, 2024-07-03:
Thanks again.  I've been taking your underlying source for the VGA and I've added sprite support, PETSCII graphics, text scrolling, etc.

I'm easily pushing 20 sprites per scanline.  Each sprite is 16xYY pixels tall (height definable) and 4 colors like NES (out of multiple palettes) all while on a 256 display.  This $4 Pico (RP2040) is incredible.

Closed 2024-07-01.

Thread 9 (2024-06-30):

BGR vs RGB

cbmeeks, 2024-06-30:
I am curious on how I can change the library to encode pixels as RGB instead of BGR.

I realize I could just swap the wires around (blue pins send to red, etc.) but that doesn't feel right.  Also, when I look at the graphic you have the red pins starting on left.

Is there a way to change this in the code or do I just need to rewire things?

Thanks!

```
void scanline(uint16_t y, uint16_t pixels[VGA_VIRTUAL_WIDTH]) {
    uint16_t c = 0x0000;
    if (y == 0 || y == VGA_VIRTUAL_HEIGHT - 1) c = 0x0000;
    else if (y < 30) c = 0x000f;    // red
    else if (y < 60) c = 0x00f0;    // green
    else if (y < 90) c = 0x0f00;    // blue
    else if (y < 120) c = 0x0f0f;   // fuscia
    else if (y < 150) c = 0x0ff0;   // cyan
    else if (y < 180) c = 0x00ff;   // yellow
    else if (y < 210) c = 0x007f;   // orange
    else if (y < 240) c = 0x0707;   // purple
    for (int x = 1; x < VGA_VIRTUAL_WIDTH - 1; ++x) {
        pixels[x] = c;
    }
    pixels[0] = 0x0000;
    pixels[VGA_VIRTUAL_WIDTH - 1] = 0x0000;
}
```

visrealm, 2024-06-30:
I don't think this can be changed in code. I thought perhaps `sm_config_set_out_shift()` which as a `shift_right` argument, but that doesn't appear to do what I had hoped it would. LSB seems to always be mapped to the lowest IO pin number in the group.

If you must use RGB, I think swapping the R and B pins on the VGA is your best bet.

cbmeeks, 2024-06-30:
Thanks!  I can do that.

Closed 2024-06-30.

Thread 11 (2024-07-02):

Ground plane

sweetlilmre, 2024-07-02:
Hi there again!

First off not a major issue, so let me start with this:
What a fantastic kit! Super well packaged, labelled and straight forward. My pico-56 is working and I'm amped to get into playing with it. I was lucky enough to to have a mate visiting from Oz that could bring it over for me.

While I was soldering up the board, I had some issues with components connected to the ground plane. I have a good temp controlled iron with a medium chisel tip and good thermal mass, that I usually run at 330C. This wasn't sufficient to create a good joint on certain components e.g. some caps, resistors, a transistor leg, pins on some connectors etc. I ended up having to boost the temp up to about 390-400C with uncomfortably long dwell times.

If I'm the only one with this issue, then tough for me, but I would suggest revising the PCB so that the these components are connected via traces through an island to the ground plane to make assembly easier.

Thanks for the awesome project.

visrealm, 2024-07-03:
Thanks Peter.

You are the second person to mention this. The other was one of the giveaway winners.

I run a TS-100 with the BC2 tip at 375C. I haven't had the same issues having assembled ~25 of these, but certainly can see that it could be a problem.

If I make another revision of the board, I will certainly look to reduce the ground plane to pad connection thickness.

sweetlilmre, 2024-07-03:
Thank you, I'll close this.

Closed 2024-07-03.

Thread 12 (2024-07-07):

How does the audio emulation work?

cbmeeks, 2024-07-07:
I realize you forked the emu2149 library and added more code for the Pico.

It seems to be pretty straightforward to get the audio piece to work (using AY-3-8910 mode).  However, nothing seems to work on my setup.

I suspect that you have to call the `audioUpdate()` very quickly?  I believe you are calling it at the end of each horizontal scanline.
Unfortunately, that won't work for my project as I need a more "general purpose" implementation (called from a 6502).

At the very least, what I am doing is something like:

    // setup code
    audioInit(3579545 / 2, 44100);
    audioWritePsg0(7, 0b00111110);
    audioWritePsg0(8, 0b00001111);

    // main loop
     audioWritePsg0(0, 223);
    audioWritePsg0(1, 1);
    audioUpdate();

I really just got those register values from a YouTube video where a guy controls a real AY with an Arduino (which I did years ago).

Do you know what I am missing?

Thanks for any input.

visrealm, 2024-07-07:
audioUpdate() needs to be called at a regular frequency matching the sampleRate. You can call it more frequently,  but you'd need to buffer the psg->ch_out values after each call and apply them to your pwm outputs at a regular frequency.
If you can't use the hsync, you'll need to either use a timer or poll the current time and update the pwm values when the next sample is due.

visrealm, 2024-07-07:
Also, audioWritePsg0() doesn't work like your example expects. It's set up like the PSG is on the bus. To write a register value requires two calls to audioWritePsg0() just like the real device. First with LSB of 0 to set the register number, then with an LSB of 1 to set the value.

So,

audioWritePsg0(7, 0b00111110);

Should be

audioWritePsg0(0, 7);
audioWritePsg0(1, 0b00111110);

Seems odd, but that's what my HBC-56 has to do to write to a PSG (except 0 and 1 are replaced with the physical address of the PSG). The underlying library has a function  to write a value to a register in one call though.

cbmeeks, 2024-07-07:
OK, I think that makes sense.  Years ago I controlled a real AY-3-8910 with an Arduino and the difference here is that it had a real clock.  Since this is in software, we basically have to emulate that.

I will give that a shot.

Thanks again!

cbmeeks, 2024-07-07:
For those that might be interested, this seems to work!

At a sample rate of 44,100 Hz, I used the following:

1000 (ms) / 44100 = 0.022675737
0.022675737 * 1000 (uS) = 22.675736961 uS

I rounded up and just used a 23uS repeating timer:

    bool repeating_timer_callback(struct repeating_timer *t) {
        audioUpdate();
        return true;
    }

    add_repeating_timer_us(23, repeating_timer_callback, NULL, &timer);

    while (1) {

        // plays a middle A (440)
        audioWritePsg0(0, 0);   // register 0
        audioWritePsg0(1, 28);   // register 0 value

        audioWritePsg0(0, 1);   // register 1
        audioWritePsg0(1, 1);   // register 1 value

        sleep_ms(500);
    }

cbmeeks, 2024-07-07:
> audioUpdate() needs to be called at a regular frequency matching the sampleRate. You can call it more frequently, but you'd need to buffer the psg->ch_out values after each call and apply them to your pwm outputs at a regular frequency. If you can't use the hsync, you'll need to either use a timer or poll the current time and update the pwm values when the next sample is due.

I'm playing some VGM music but something is off.  It only works if I stream the registers/data at the same rate of the `audioUpdate`.  Is that correct?  Basically, does the audioUpdate the only thing that needs to be called at the same frequency or does sending commands also have to be at that rate?

Thanks.

visrealm, 2024-07-08:
Note the MSX2 had the YM2149, so it might be that it hasn't been initialized as a YM2149, but rather an AY-3-8910. You might have changed this already, but just in case...

See this from the README:
```

/* Typical YM2149 configuration */
PSG *psg = PSG_new(3579545, 44100);
PSG_setClockDivider(psg, 1);
PSG_setVolumeMode(psg, 1); // YM style
PSG_reset();

/* Typical AY-3-8910 configuration */
PSG *psg = PSG_new(3579545/2, 44100);
PSG_setVolumeMode(psg, 2); // AY style
PSG_reset();
```

cbmeeks, 2024-07-08:
Ah, I didn't see the `PSG_setClockDivider` method.  Also, it's not exposed in the header file of emu2149.h that I saw but I corrected it.

I did originally try setting the volume mode to the AY but didn't notice a difference.

I have a project that uses the library and plays a VGM song if you want to listen for yourself.

Either way, I will continue messing around with this library as I really like having it in my project.  :-)

https://github.com/cbmeeks/PicoSnd

Closed 2024-07-07.

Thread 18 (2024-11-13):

Nonfunctioning PS2 keyboard connection

amishrabbit, 2024-11-13:
Hey there. I built the PICO-56 kit that was sold through Hackerboxes. The unit has been flashed to the v 0.5 firmware and boots, but I have tested it with two known-functional PS/2 keyboards and the device does not seem to detect or recognize the keyboards, or there may be some other problem. The keytest.o applet cannot proceed because the device does not recognize any keys, nor do any of the lights on the keyboard function.

The Hackerboxes kit came with a classic NES gamepad, and that gamepad does function and is able to operate in the test apps.

How do I diagnose what is the root cause of this issue with the PS/2 keyboard or connector? I have closely inspected the solder joints on the PS/2 connector and they appear to be functional and not bridged. What other parts on the device could be at fault?

visrealm, 2024-11-13:
Hi,
The keyboard is powered (grounded) via the transistor Q1. This transistor also has very fine pin pitch on the board and is very easy to bridge. Could you check the transistor connections?
When you turn the PICO-56 on, do the indicator lights on the keyboard flash once or not at all?
Cheers
Troy

amishrabbit, 2024-11-17:
Hi Troy. When I power on the device, the blue SD indicator LED flashes once, the blue PWR LED on the board and the red PWR LED on the Pi remain lit steadily and do not flash.

I will inspect the Q1 transistor connections with a microscope; they look good but that's good info to check.

visrealm, 2024-11-18:
Thanks. I was meaning the LEDs on the keyboard (Num lock, Caps lock, Scroll lock). They usually flash once at startup for most keyboards. If that's not happening, then it's likely a power issue (possibly Q1)

Animapix, 2024-11-24:
Hi, I have the same issue with my keyboard. I checked all the soldering connections under a microscope, and they all seem to be good.
I'm using a USB ANSI keyboard with a US layout and a PS/2 adapter. I’m not sure if the issue is caused by the keyboard's power consumption or the USB/PS2 adapter.

visrealm, 2024-11-25:
@Animapix I've tested mine with an old PS/2 keyboard which draws 400mA and it's fine.  I'd say it's the adapter. Is the keyboard designed to work with an adapter? The adapters will only work if the keyboard supports PS/2 protocol.

Animapix, 2024-11-25:
Thank you for your response, @visrealm.

I tested the current consumption of my keyboard, which is 432 mA, so that seemed fine. However, as you pointed out, I checked and found that my keyboard is indeed not compatible with PS/2. I’m sorry for bothering you over something so simple! I'll order a compatible keyboard instead.

Thank you so much for all the work you’ve done on this impressive project. I'm continuing to explore how it works, and I must say, diving into retro computing has been quite a challenge, but also incredibly fascinating.

Thanks again!

visrealm, 2024-12-04:
Any update @amishrabbit  ?

visrealm, 2024-12-10:
Dead issue

Closed 2024-12-10.

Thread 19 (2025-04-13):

submodules/sdcard @ f694280 is directed to a missing project

3vi1, 2025-04-13:
Downloaded and was init'ing submodules to find:

fatal: remote error: upload-pack: not our ref f694280c330e707d28fa42f538028dae694abe3d
fatal: Fetched in submodule path 'submodules/sdcard', but it did not contain f694280c330e707d28fa42f538028dae694abe3d. Direct fetching of that commit failed.

https://github.com/visrealm/no-OS-FatFS-SD-SDIO-SPI-RPi-Pico/tree/f694280c330e707d28fa42f538028dae694abe3d does not seem to exist.

3vi1, 2025-04-16:
Looks like it was either a temporary github issue throwing the 404, or you fixed it.  Thanks!

Closed 2025-04-16.

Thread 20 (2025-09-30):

Weird Keyboard behaviour.

bartleph, 2025-09-30:
I have built my own PCB and constructed your excellent 65C02 on a Pico. When running the examples, some prompt "Press Any Key" and others Prompt "Press the 'A' key".  I am finding that the program examples asking for a "Press the 'A' key" are not seeing the keypress. I have run the keyboard test, and all the keys appear as they should, and the examples asking for "Press any Key" work perfectly even pressing 'A'.

A suggestion too, would it be possible to cater for an English Keyboard in the source or config??

Thanks for a great project which worked beautifully first time, apart from my keyboard issue.!!

Closed 2025-09-30.

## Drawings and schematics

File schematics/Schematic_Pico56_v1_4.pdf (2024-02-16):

## MICRO SD-CARD

## NES

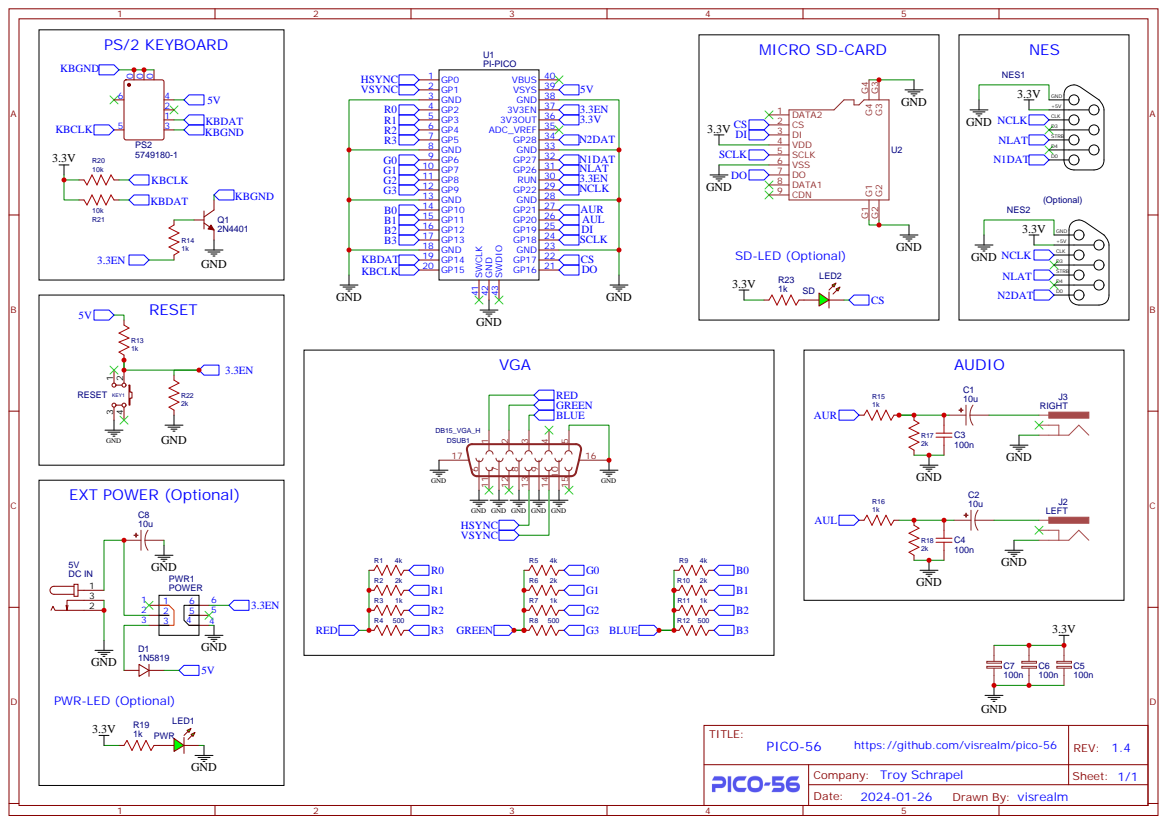
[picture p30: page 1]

GND GND GND GND GND
HSYNC
VSYNC

https://github.com/visrealm/pico-56

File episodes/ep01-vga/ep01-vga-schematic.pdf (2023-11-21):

A | A

1

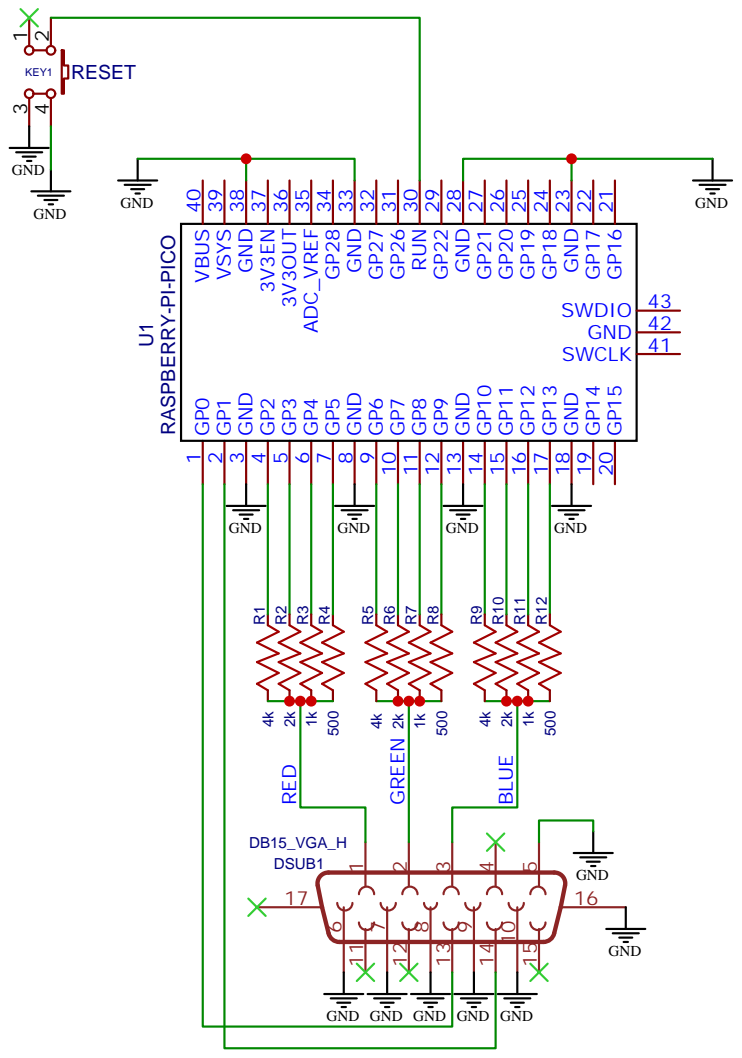
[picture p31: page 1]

GP15 20 GP17 22 GND 23 GP18 24 GP19 25 GP20 26 GP21 27 GND 28 GP22 29 RUN 30 GP26 31 GP27 32 GND 33 GP28 34 ADC_VREF 35 3V3OUT 36 3V3EN 37 GND 38 VSYS 39 VBUS 40

GND GND GND GND GND

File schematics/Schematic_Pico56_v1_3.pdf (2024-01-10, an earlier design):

## SD-CARD

## NES

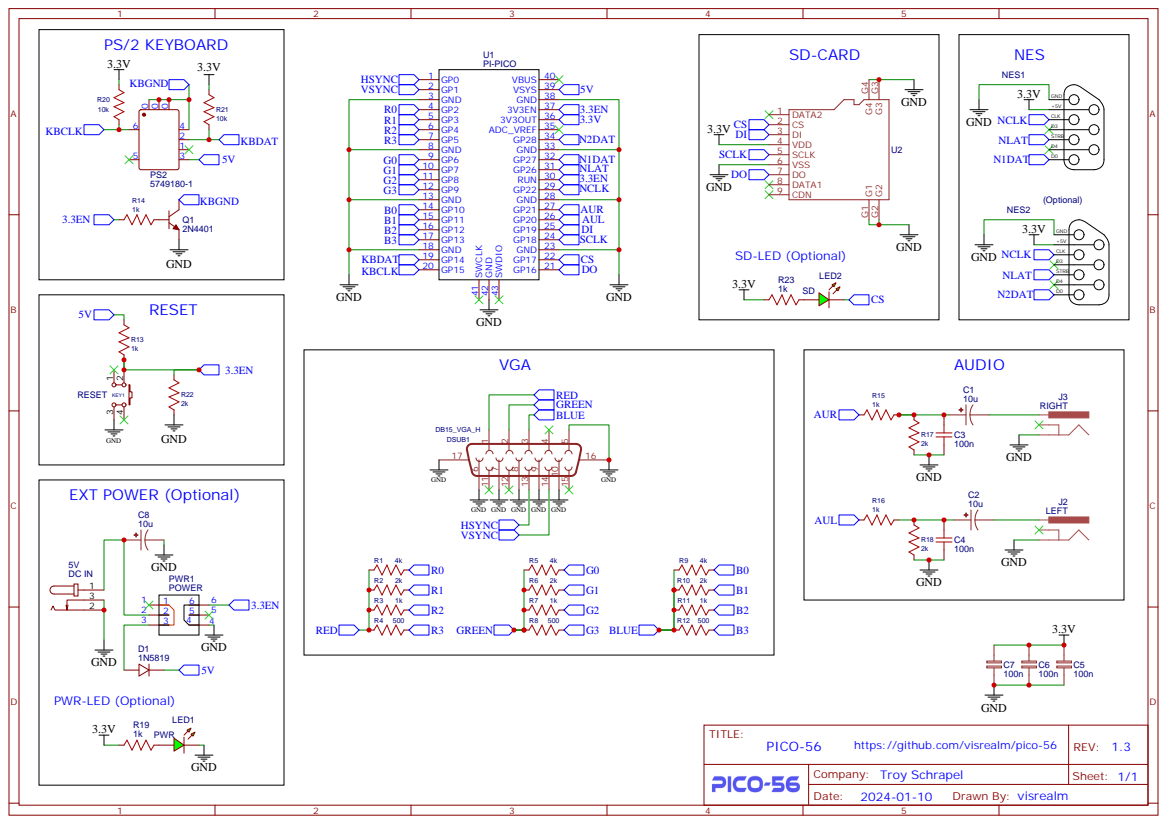
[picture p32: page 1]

GND GND GND GND GND
HSYNC
VSYNC

https://github.com/visrealm/pico-56

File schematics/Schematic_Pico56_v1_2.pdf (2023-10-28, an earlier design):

## SD-CARD

## NES

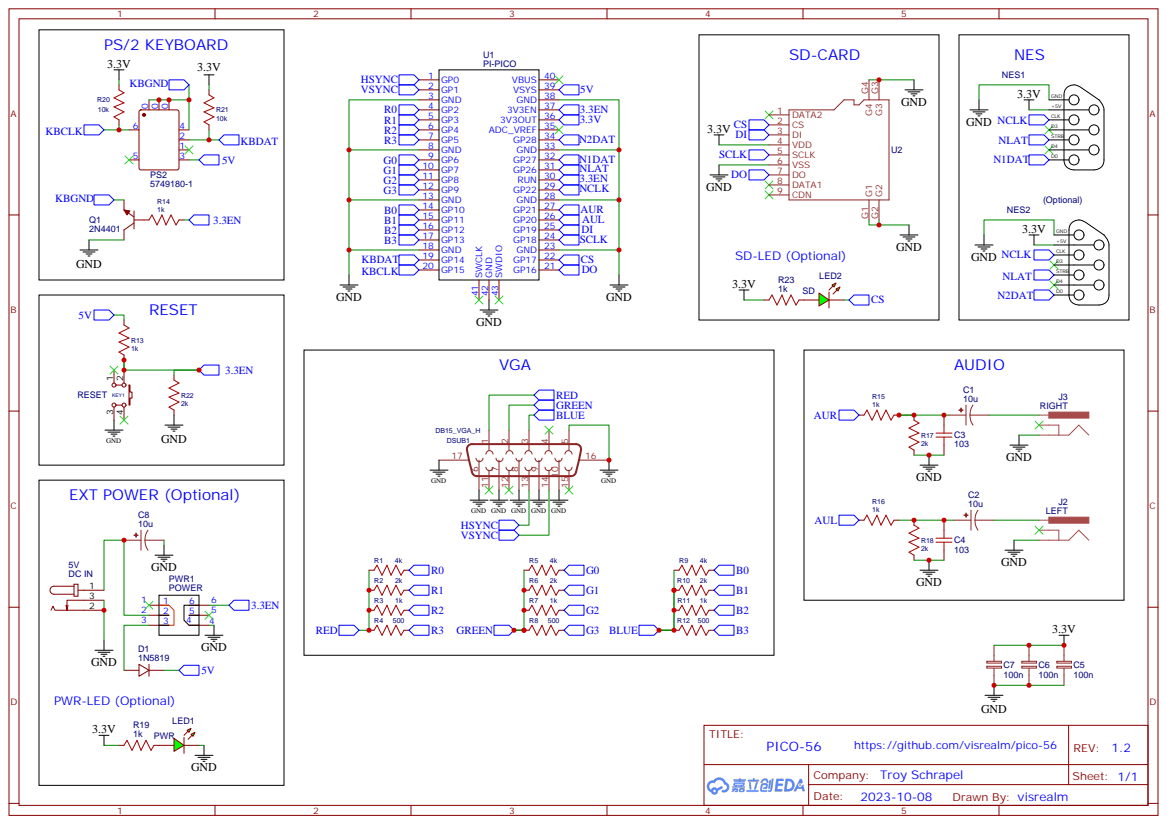
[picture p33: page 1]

GND GND GND GND GND
HSYNC
VSYNC

https://github.com/visrealm/pico-56

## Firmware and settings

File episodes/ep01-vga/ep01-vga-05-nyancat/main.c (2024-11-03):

/*
 * Project: pico-56 - episode 1
 *
 * Copyright (c) 2023 Troy Schrapel
 *
 * This code is licensed under the MIT license
 *
 * https://github.com/visrealm/pico-56
 *
 */

#include "vga.h"
#include "images.h"

#include "pico/stdlib.h"
#include "hardware/clocks.h"

#include <memory.h>

typedef struct
{
  int xPos;
  int yPos;
  int frame;
  int animDir;
} NyanStar;

#define NYAN_WIDTH 128
#define NYAN_HEIGHT 80

#define STAR_WIDTH 21
#define STAR_HEIGHT 21
#define STAR_SPEED -21

#define RAINBOW_WIDTH 34
#define RAINBOW_HEIGHT 60

#define NYAN_FRAME_RPT 4
#define RAINBOW_FRAME_RPT 12
#define STAR_FRAME_RPT 3

#define RAINBOW_POS_Y 80
#define RAINBOW_POS_X -9
#define RAINBOW_OFFSET_Y 3
#define RAINBOW_RPT 4

#define NYAN_POS_X  90
#define NYAN_POS_Y  71

void nyanScanline(uint16_t y, uint16_t pixels[VGA_VIRTUAL_WIDTH])
{
  static int frame = 0;
  const uint16_t backColor = 0x0741;
  static NyanStar stars[] = { {140, -6, 0, 1},{250, 26, 1, 1},{310, 66, 2, 1},{0, 135, 3, 1},{265, 185, 3, -1},{100, 219, 4, 1} };
  static int nyanFrame = 0;

  const uint16_t* nyanFrames[] = { nyan00,nyan01,nyan02,nyan03,nyan04,nyan05 };
  const uint16_t* starFrames[] = { nyanstar00,nyanstar01,nyanstar02,nyanstar03,nyanstar04,nyanstar05 };

  const int numNyanFrames = sizeof(nyanFrames) / sizeof(uint16_t*);
  const int numStarFrames = sizeof(starFrames) / sizeof(uint16_t*);
  const int numStars = sizeof(stars) / sizeof(NyanStar);

  // output the background
  for (int x = 0; x < VGA_VIRTUAL_WIDTH; ++x)
  {
    pixels[x] = backColor;
  }

  // output the rainbow
  if (y >= RAINBOW_POS_Y && y <= (RAINBOW_POS_Y + RAINBOW_HEIGHT + RAINBOW_OFFSET_Y))
  {
    int rainbowFrame = (frame / RAINBOW_FRAME_RPT) & 1;

    int destX = 0;
    for (int i = 0; i < RAINBOW_RPT; ++i)
    {
      int xFrame = i & 1;
      int srcY = y - RAINBOW_POS_Y;
      if (xFrame == rainbowFrame) srcY -= RAINBOW_OFFSET_Y;

      int srcWidth = RAINBOW_WIDTH;
      if (i == 0) srcWidth += RAINBOW_POS_X;
      int srcOffset = ((srcY + 1) * RAINBOW_WIDTH) - srcWidth;

      if (srcY >= 0 && srcY < RAINBOW_HEIGHT)
      {
        memcpy(pixels + destX, nyanrainbow + srcOffset, srcWidth * sizeof(uint16_t));
      }
      destX += srcWidth;
    }
  }

  // output the stars
  for (int i = 0; i < numStars; ++i)
  {
    if (y >= stars[i].yPos && y < (stars[i].yPos + STAR_HEIGHT))
    {
      int startPixel = (y - stars[i].yPos) * STAR_WIDTH;
      for (int x = 0; x < STAR_WIDTH; ++x)
      {
        int pixelX = stars[i].xPos + x;
        if (pixelX < 0 || pixelX >= VGA_VIRTUAL_WIDTH) continue;
        uint16_t c = starFrames[stars[i].frame][startPixel + x];
        if (c & 0xf000)
        {
          pixels[pixelX] = c;
        }
      }
    }
  }

  // output the cat
  if (y >= NYAN_POS_Y && y < (NYAN_POS_Y + NYAN_HEIGHT))
  {
    int srcOffset = (y - NYAN_POS_Y) * NYAN_WIDTH;
    for (int x = 0; x < NYAN_WIDTH; ++x)
    {
      uint16_t c = nyanFrames[nyanFrame][srcOffset + x];
      if (c & 0xf000)
      {
        pixels[x + NYAN_POS_X] = c;
      }
    }

  }

  // end of frame updates
  if (y == VGA_VIRTUAL_HEIGHT - 1)
  {
    ++frame;

    if ((frame % STAR_FRAME_RPT) == 0)
    {
      for (int i = 0; i < numStars; ++i)
      {
        stars[i].xPos += STAR_SPEED;
        if (stars[i].xPos < -STAR_WIDTH)
        {
          stars[i].xPos += VGA_VIRTUAL_WIDTH;
        }
        stars[i].frame += stars[i].animDir;
        if (stars[i].frame < 0) stars[i].frame = numStarFrames - 1;
        else if (stars[i].frame >= numStarFrames) stars[i].frame = 0;
      }
    }

    if ((frame % NYAN_FRAME_RPT) == 0)
    {
      ++nyanFrame;
      nyanFrame %= numNyanFrames;
    }
  }
}
int main(void)
{
  set_sys_clock_khz(252000, false);

  VgaInitParams params;
  params.scanlineFn = nyanScanline;

  vgaInit(params);

  while (1)
  {
    tight_loop_contents();
  }

  return 0;
}

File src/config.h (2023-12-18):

/*
 * Troy's HBC-56 Emulator
 *
 * Copyright (c) 2021 Troy Schrapel
 *
 * This code is licensed under the MIT license
 *
 * https://github.com/visrealm/hbc-56/emulator
 *
 */


#ifndef _HBC56_CONFIG_H_
#define _HBC56_CONFIG_H_


/* emulator configuration values 
  -------------------------------------------------------------------------- */
#define HBC56_HAVE_THREADS      0

#define HBC56_CLOCK_FREQ        3686400   /* half of 7.3728 */
#define HBC56_AUDIO_FREQ        48000
#define HBC56_MAX_DEVICES       16

/* memory map configuration values 
  -------------------------------------------------------------------------- */
#define HBC56_RAM_START         0x0000
#define HBC56_RAM_SIZE          0x7f00

#define HBC56_ROM_START         0x8000
#define HBC56_ROM_SIZE          0x8000

#define HBC56_IO_START          0x7f00
#define HBC56_IO_SIZE           0x0100

/* device configuration values 
  -------------------------------------------------------------------------- */
#define HBC56_HAVE_TMS9918      1
#define HBC56_TMS9918_PORT      0x10
#define HBC56_TMS9918_DAT_PORT  HBC56_TMS9918_PORT
#define HBC56_TMS9918_REG_PORT (HBC56_TMS9918_PORT | 0x01)
#define HBC56_TMS9918_IRQ      1

#define HBC56_HAVE_LCD          0
#define HBC56_LCD_PORT          0x02
#define HBC56_LCD_CMD_PORT      HBC56_LCD_PORT
#define HBC56_LCD_DAT_PORT     (HBC56_LCD_PORT | 0x01)

#define HBC56_HAVE_NES          1
#define HBC56_NES_PORT          0x82

#define HBC56_HAVE_KB           1
#define HBC56_KB_PORT           0x80
#define HBC56_KB_IRQ            2

#define HBC56_HAVE_AY_3_8910    1
#define HBC56_AY_3_8910_COUNT   2
#define HBC56_AY38910_A_PORT    0x40
#define HBC56_AY38910_B_PORT    0x44
#define HBC56_AY38910_CLOCK     2000000

#define HBC56_HAVE_VIA          1
#define HBC56_VIA_PORT          0xf0
#define HBC56_VIA_IRQ           5

#define HBC56_IRQ_PORT          0xdf

#ifdef _WINDOWS
#define HBC56_HAVE_UART         1
#endif
#define HBC56_UART_PORT         0x20
#define HBC56_UART_PORTNAME     "COM7"
#define HBC56_UART_CLOCK_FREQ   HBC56_CLOCK_FREQ
#define HBC56_UART_IRQ          3

/* computed configuration values (shouldn't need to touch these) 
  -------------------------------------------------------------------------- */
#define HBC56_RAM_END           (HBC56_RAM_START + HBC56_RAM_SIZE) /* one past end */
#define HBC56_ROM_END           (HBC56_ROM_START + HBC56_ROM_SIZE) /* one past end */
#define HBC56_IO_PORT_MASK      (HBC56_IO_SIZE - 1)

#define HBC56_IO_ADDRESS(p)     (HBC56_IO_START | (p & HBC56_IO_PORT_MASK))


#endif

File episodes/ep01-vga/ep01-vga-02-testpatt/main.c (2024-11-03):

/*
 * Project: pico-56 - episode 1
 *
 * Copyright (c) 2023 Troy Schrapel
 *
 * This code is licensed under the MIT license
 *
 * https://github.com/visrealm/pico-56
 *
 */

#include "vga.h"

#include "pico/stdlib.h"
#include "hardware/clocks.h"

int addColor(int r, int g, int b, int y, int count, uint16_t* pixels)
{
  r += (y - 120) * 2.125;
  g += (y - 120) * 2.125;
  b += (y - 120) * 2.125;
  if (r < 0) r = 0; if (r > 255) r = 255;
  if (g < 0) g = 0; if (g > 255) g = 255;
  if (b < 0) b = 0; if (b > 255) b = 255;

  for (int i = 0; i < count; ++i)
  {
    pixels[i] = ((b & 0xf0) << 4) | ((g & 0xf0)) | ((r & 0xf0) >> 4);
  }

  return count;
}

int addColorMild(int r, int g, int b, int y, int count, uint16_t* pixels)
{
  r -= (y - 120) * 1.0625;
  g -= (y - 120) * 1.0625;
  b -= (y - 120) * 1.0625;
  if (r < 0) r = 0; if (r > 255) r = 255;
  if (g < 0) g = 0; if (g > 255) g = 255;
  if (b < 0) b = 0; if (b > 255) b = 255;

  for (int i = 0; i < count; ++i)
  {
    pixels[i] = ((b & 0xf0) << 4) | ((g & 0xf0)) | ((r & 0xf0) >> 4);
  }

  return count;
}


void testPatternFunc(uint16_t y, uint16_t pixels[VGA_VIRTUAL_WIDTH])
{
  static int offset = 0;

  int x = 1;
  int r = 0, g = 0, b = 0;

  const uint16_t borderColor = 0x0f00;

  if (y == 0 || y == VGA_VIRTUAL_HEIGHT - 1)
  {
    for (int i = 0; i < VGA_VIRTUAL_WIDTH; ++i)
    {
      pixels[i] = borderColor;
    }
    return;
  }

  int pixelsPerBand = 11;

  x += addColorMild(127, 127, 127, y, 54, pixels + x);
  x += addColor(255, 0, 0, y, pixelsPerBand, pixels + x);
  x += addColor(255, 63, 0, y, pixelsPerBand, pixels + x);
  x += addColor(255, 127, 0, y, pixelsPerBand, pixels + x);
  x += addColor(255, 192, 0, y, pixelsPerBand, pixels + x);
  x += addColor(255, 255, 0, y, pixelsPerBand, pixels + x);
  x += addColor(192, 255, 0, y, pixelsPerBand, pixels + x);
  x += addColor(127, 255, 0, y, pixelsPerBand, pixels + x);
  x += addColor(63, 255, 0, y, pixelsPerBand, pixels + x);
  x += addColor(0, 255, 0, y, pixelsPerBand, pixels + x);
  x += addColor(0, 255, 63, y, pixelsPerBand, pixels + x);
  x += addColor(0, 255, 127, y, pixelsPerBand, pixels + x);
  x += addColor(0, 255, 192, y, pixelsPerBand, pixels + x);
  x += addColor(0, 255, 255, y, pixelsPerBand, pixels + x);
  x += addColor(0, 192, 255, y, pixelsPerBand, pixels + x);
  x += addColor(0, 127, 255, y, pixelsPerBand, pixels + x);
  x += addColor(0, 63, 255, y, pixelsPerBand, pixels + x);
  x += addColor(0, 0, 255, y, pixelsPerBand, pixels + x);
  x += addColor(63, 0, 255, y, pixelsPerBand, pixels + x);
  x += addColor(127, 0, 255, y, pixelsPerBand, pixels + x);
  x += addColor(192, 0, 255, y, pixelsPerBand, pixels + x);
  x += addColor(255, 0, 255, y, pixelsPerBand, pixels + x);
  x += addColor(255, 0, 192, y, pixelsPerBand, pixels + x);
  x += addColor(255, 0, 127, y, pixelsPerBand, pixels + x);
  x += addColor(255, 0, 63, y, pixelsPerBand, pixels + x);
}

int main(void)
{
  set_sys_clock_khz(126000, false);

  VgaInitParams params;
  params.scanlineFn = testPatternFunc;

  vgaInit(params);

  while (1)
    tight_loop_contents();

  return 0;
}

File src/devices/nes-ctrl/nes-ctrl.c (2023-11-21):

/*
 * Project: pico-56 - NES controller
 *
 * Copyright (c) 2023 Troy Schrapel
 *
 * This code is licensed under the MIT license
 *
 * https://github.com/visrealm/pico-56
 *
 */

#include "nes.pio.h"

static PIO pio = pio1;
static uint8_t sm = -1;

#define NES_LATCH_GPIO 26
#define NES_CLOCK_GPIO 22
#define NES1_DATA_GPIO 27
#define NES2_DATA_GPIO 28

static uint8_t nes_state_1 = 0xff;
static uint8_t nes_state_2 = 0xff;

/*
 * return NES1 state
 */
uint8_t nes_get_state_1()
{
  return nes_state_1;
}

/*
 * return NES2 state
 */
uint8_t nes_get_state_2()
{
  return nes_state_2;
}

/*
 * start dual NES PIO
 */
bool nes_begin()
{
  if (pio_can_add_program(pio, &nes_program) &&
    ((sm = pio_claim_unused_sm(pio, true)) >= 0)) {
    uint offset = pio_add_program(pio, &nes_program);
    pio_sm_config c = nes_program_get_default_config(offset);

    sm_config_set_sideset_pins(&c, NES_CLOCK_GPIO);
    sm_config_set_in_pins(&c, NES1_DATA_GPIO);
    sm_config_set_set_pins(&c, NES_LATCH_GPIO, 1);
    pio_gpio_init(pio, NES_CLOCK_GPIO);
    pio_gpio_init(pio, NES1_DATA_GPIO);
    pio_gpio_init(pio, NES2_DATA_GPIO);
    pio_gpio_init(pio, NES_LATCH_GPIO);

    gpio_pull_up(NES1_DATA_GPIO);
    gpio_pull_up(NES2_DATA_GPIO);

    pio_sm_set_pindirs_with_mask(pio, sm,
      (1 << NES_CLOCK_GPIO) | (1 << NES_LATCH_GPIO), // Outputs
      (1 << NES_CLOCK_GPIO) | (1 << NES1_DATA_GPIO) | (1 << NES2_DATA_GPIO) |
      (1 << NES_LATCH_GPIO)); // All pins
    sm_config_set_in_shift(&c, false, true, 16); // L shift, autopush @ 16 bits

    sm_config_set_clkdiv(&c, 266.0);

    // IRQ is just a 'go' flag, don't assert a system interrupt
    pio_set_irq0_source_enabled(
      pio, (enum pio_interrupt_source)(pis_interrupt0 + sm), false);

    pio_sm_clear_fifos(pio, sm);

    pio_sm_init(pio, sm, offset, &c);
    pio_sm_set_enabled(pio, sm, true);

    return true; // Success
  }
  return false;
}

/*
 * initiate dual NES read
 */
void nes_read_start(void)
{
  pio_interrupt_clear(pio, 0);
}

/*
 * complete dual NES read
 */
void nes_read_finish(void)
{
  uint32_t value = (sm >= 0) ? pio_sm_get_blocking(pio, sm) : 0xffff;

  uint8_t value1 = 0x00, value2 = 0x00;
  uint8_t mask = 0x01;

  for (int i = 0; i < 8; ++i)
  {
    value1 |= value & mask;
    value >>= 1;
    value2 |= value & mask;
    mask <<= 1;
  }
  nes_state_1 = value1;
  nes_state_2 = value2;
}

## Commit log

2023-11-14 Added Gerber
2023-11-20 PICO-56 Code: Initial add
2023-11-21 Reset keyboard leds once rom loaded
    [bus.c, ps2-kbd.c]
2023-11-28 Initial sdcard hbc-56 device support
2023-12-02 Fixed boing demo - store background in ram rather than flash
    [main.c]
2023-12-18 Added Uart support
2024-01-10 Updated schematics and gerber to v1.3
2024-01-27 Update README.md BOM
2024-02-16 Added v1.4 schematic and gerber
2024-03-09 Added case STLs
    [p56-badge-v1-5.stl, p56-bottom-v1-5.stl, p56-power-v1-5.stl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]
2024-03-09 Case pics
2024-03-09 Case images
2024-04-07 Fixed debug build due to incompatibility in type returned from get_absolute_time() between DEBUG and RELEASE. See https://forums.raspberrypi.com/viewtopic.php?t=329297
    [bus.c]
2024-10-26 Updated to Pi Pico VSCode plugin
2024-10-26 Updated to Pico SDK v2.0
2024-11-03 Updated to v0.5. Switch to pico by default
2024-11-03 Switch back to pico by default
2025-09-14 github actions to build pico and pico2 versions on windows, linux and macos
2026-01-29 test
    Updated build workflow to install ARM GNU Toolchain and modified dependency installation.
2026-01-29 gha
    Removed installation of ARM GNU Toolchain and replaced it with gcc-arm-embedded installation.
2026-01-29 gcc-arm-embedded from chololatey is broken :(
    Replaced gcc-arm-embedded installation with ARM GNU Toolchain download and extraction.
2026-05-01 Revise PICO-56 kit purchase details in README
    Updated the purchasing information for PICO-56 kits and added links to Lectronz.
